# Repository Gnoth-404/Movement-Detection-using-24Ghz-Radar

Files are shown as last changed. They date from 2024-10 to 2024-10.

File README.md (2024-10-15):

# Movement-Detection-using-24Ghz-Radar
Adaptive movement detection using 24Ghz Radar and CFAR Algorithm

# Radar Movement Detection System
<p align="center">
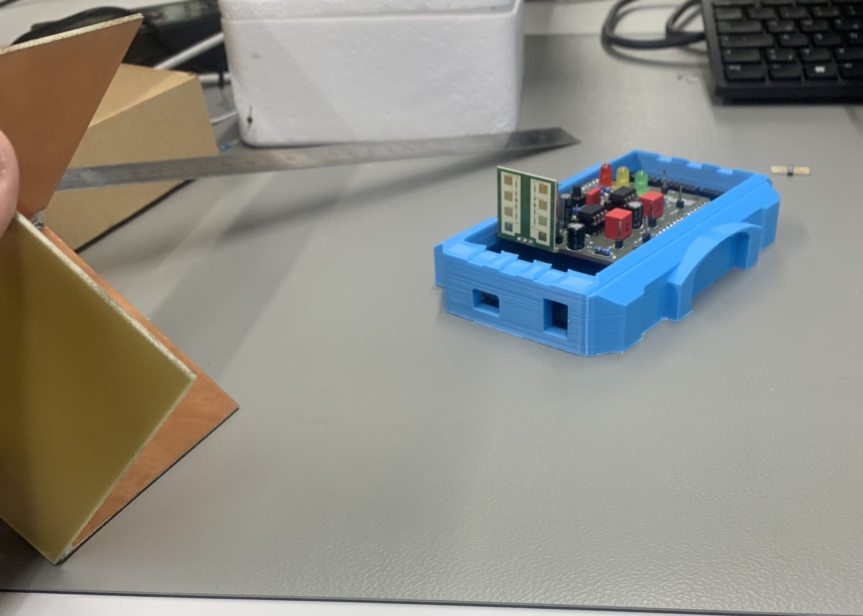
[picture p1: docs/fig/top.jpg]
  
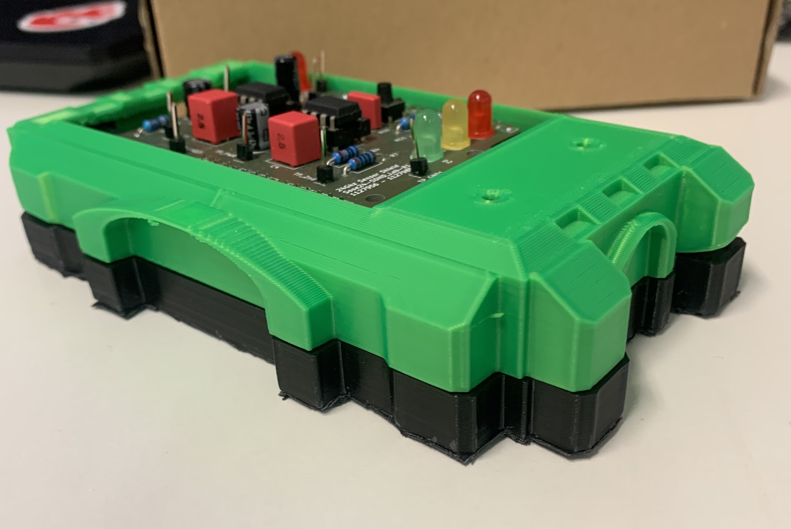
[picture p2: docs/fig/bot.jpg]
    

</p>

## Project Overview
This project implemented a radar-based movement detection system using  IPM165 radar sensor, FreeSoc2 Development Board, along with CA-CFAR algorithm. The system included custom PCB design, radar signal processing, and 3D-printed enclosure.

## Features
- 4-layer PCB design integrating IPM165 radar sensor
- Two-stage bandpass filter with gain of 300
- DMA streaming from ADC to Memory
- Signal processing using Hanning window and FFT
- Movement detection using CA-CFAR algorithm
- Custom 3D-printed enclosure

## Hardware
### PCB Design
- 4-layer PCB designed in Kicad
- Integrates IPM165 radar sensor
- Includes two-stage bandpass filter (Gain = 300)

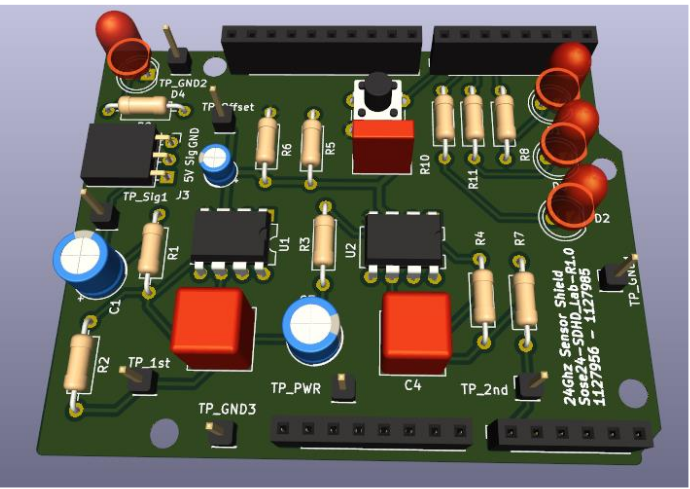
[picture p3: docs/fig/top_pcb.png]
PCB


### Enclosure
- Custom 3D-printed designed in Onshape

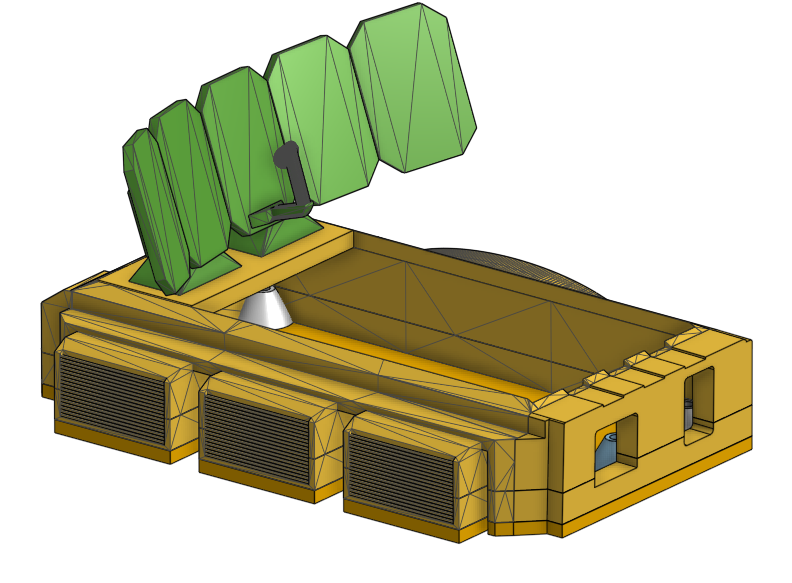
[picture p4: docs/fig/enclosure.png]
Enclosure


## Software
### Firmware (C)
- DMA streaming from ADC
- Hanning window application
- FFT implementation
- CA-CFAR algorithm for movement detection

### MATLAB
- Verification script for signal processing algorithms

## Results and Performance
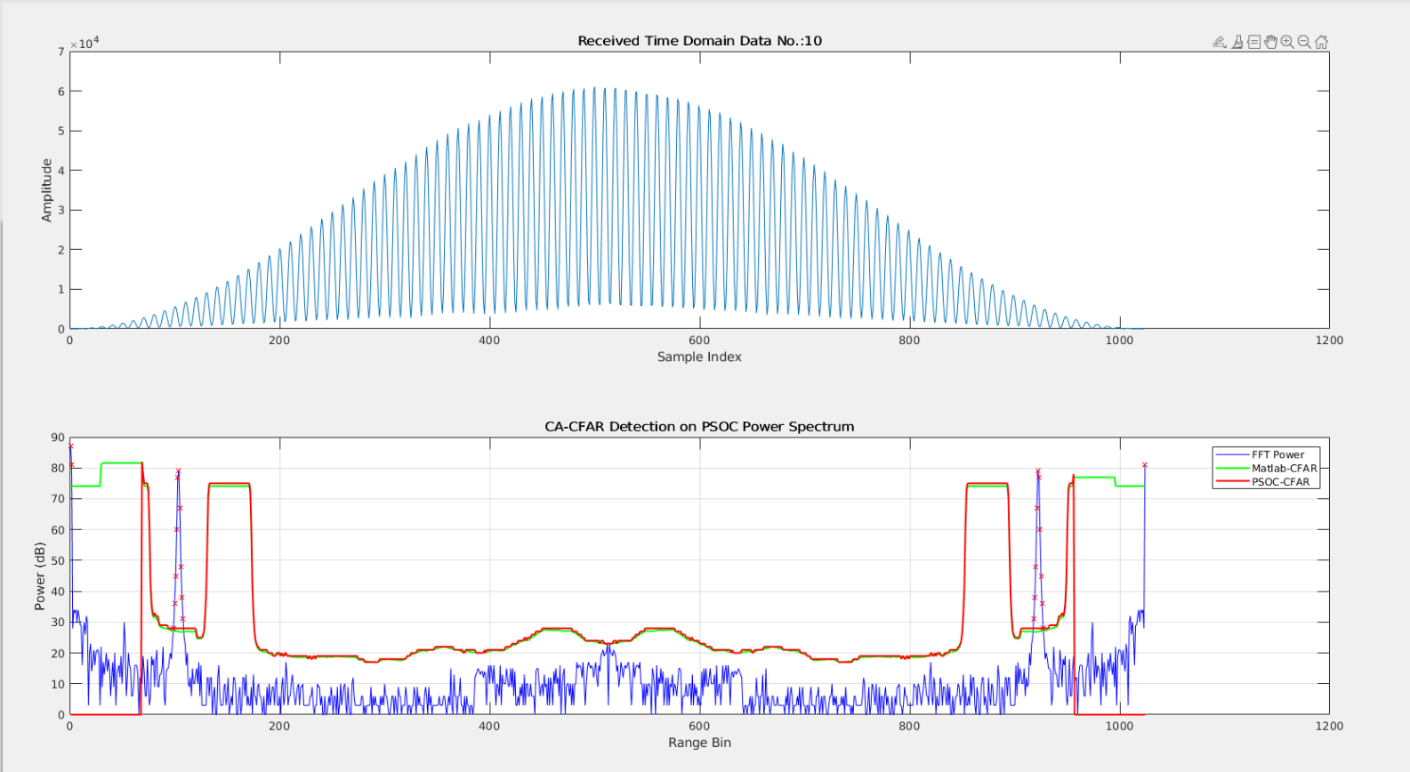
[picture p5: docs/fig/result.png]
Results


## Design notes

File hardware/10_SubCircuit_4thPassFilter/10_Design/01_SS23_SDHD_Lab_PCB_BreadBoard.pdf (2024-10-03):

# System Driven Hardware Design

### Prof. Dr.-Ing. Stephan Bannwarth

SS23

## International Master of Science

- Schematic / Layout / Breadboard-LabExcesize 1

## Agenda

### - Amplifier Schematic - PCB Constraints - Tasks - Scoring Scheme - Breadboard

SS23 | System Driven Hardware Design - © Prof. Dr.-Ing. Stephan Bannwarth | 2

### Schematic Capture: Amplifier: 4th order Bandpass

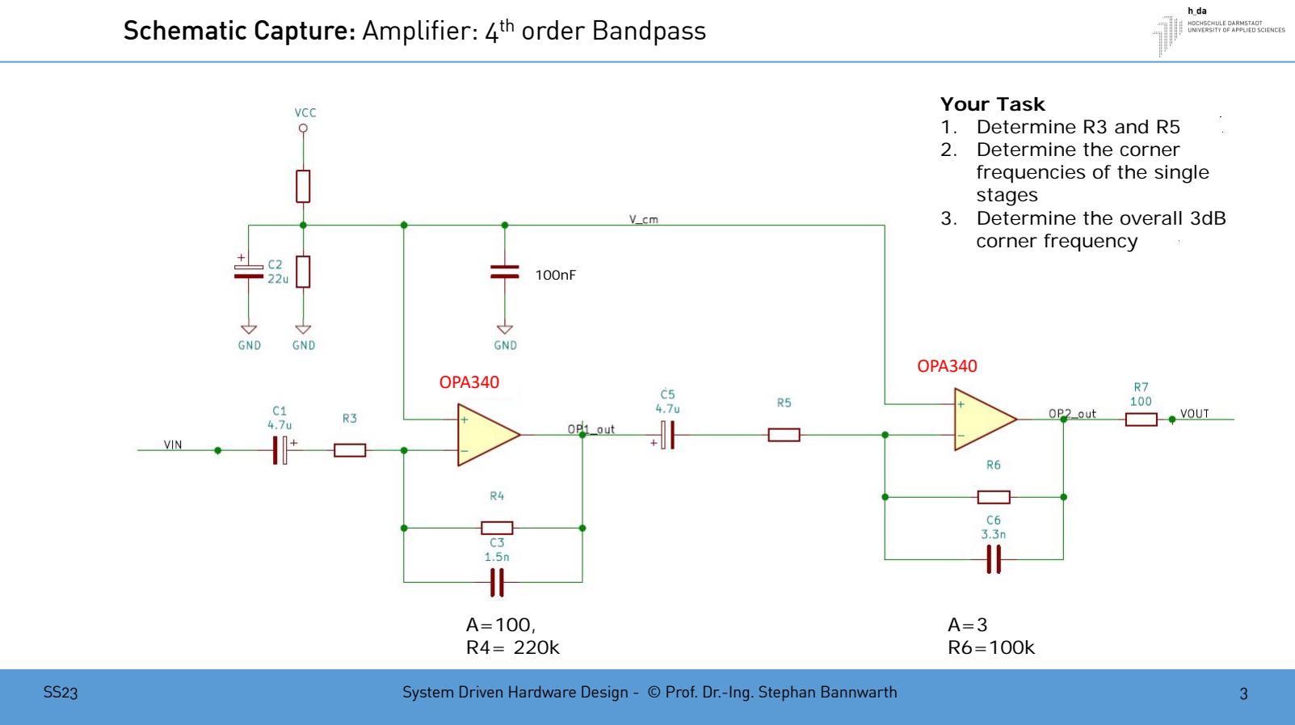
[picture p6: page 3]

SS23 | System Driven Hardware Design - © Prof. Dr.-Ing. Stephan Bannwarth | 3

100nF

A=100,
R4= 220k

A=3
R6=100k

OPA340
OPA340

Your Task
1. Determine R3 and R5
2. Determine the corner
frequencies of the single
stages
3. Determine the overall 3dB corner frequency

## Agenda

### - Amplifier Schematic - PCB Constraints - Tasks - Scoring Scheme - Breadboard

SS23 | System Driven Hardware Design - © Prof. Dr.-Ing. Stephan Bannwarth | 4

### PCB and Electronic Constraints

SS23 | System Driven Hardware Design - © Prof. Dr.-Ing. Stephan Bannwarth | 5

Amplifier
- Think about which signals should get a testpoint and write them down
- Used Device: OPA340
- Use the Operational Amplifier in a DIL8 Package
- Use an DIL8 Socket for the OpAmp

Power Supply
- Derive the Power Supply form the FreeSoc2
- Use a red LED as a control for the power supply

Hardware-Constraints
- Use a 3 pin 90° connector (i.e. connector is parallel to your board) to connect the PCB with the radar sensor
Digital Part
- Insert a Push-Button
- Use 3 LEDs (red – yellow – green) as digital control LEDs

Technology
- Use through hole technology (THT) all components.
- Use E24 series for the resistors in THT.
PCB
- Use the Arduino UNO Shield Template from KiCad. See the HowTo in Moodle.
- Separate Analog and Digital Ground as good as possible
- Stay inside the market area of the Arduino shield with your components
- Work with a 4 layer PCB: Signal – GND – Power -Signal
- Fill out the PCB Specification (Link / Elekonta Webpage)
- Only use PTH Vias: vias size 0.8mm with via drill 0.4mm
- Minimum track width: 0.20 mm
- Do not use buried vias or blind vias

### PCB and Electronic Constraints: Pin-Mapping

SS23 | System Driven Hardware Design - © Prof. Dr.-Ing. Stephan Bannwarth | 6
Bw | Pin Mapping
Lfd.Nr | Adruino - Cape / FunctionAdruino | | FreeSoc2
1 | | D0 | P[2]0
2 | | D1 | P[2]1
3 | | D2 | P[2]2
4 | | D3 | P[2]3
5 LED1 (green) | | D4 | P[2]4
6 LED2 (ornage) | | D5 | P[2]5
7 LEDe (redd) | | D6 | P[2]6
8 Push Button 9 | | D7 D8 | P[2]7 P[12]4
10 | | D9 | P[12]5
11 | | D10 | P[6]4
12 | | D11 | P[6]5
13 | | D12 | P[6]6
14 | | D13 | P6[7] & Red Use
15 | | GND | GND
16 | | AREF | NC
17 | | SDA | P[6]1
18 19 | | SCL NC | P[6]0 NC
20 | | IOREF | VDDIO_Arduino/
21 | | Reset | nReset/2 &P[12]4
22 | | 3.3V | 3.3V
23 | | 5V | 5V
24 | | GND | GND
25 | | GND | GND
26 27 Vout (Ampliffier out) | | Vin A0 | Vin/2 P15[5]
28 | | A1 | P[15]4

See Moodle for Full Table

## Agenda

### - Amplifier Schematic - PCB Constraints - Tasks - Scoring Scheme - Breadboard

SS23 | System Driven Hardware Design - © Prof. Dr.-Ing. Stephan Bannwarth | 7

### PCB and Electronic Constraints

SS23 | System Driven Hardware Design - © Prof. Dr.-Ing. Stephan Bannwarth | 8

Moodle
- Use the Project template
Tasks
- Requirement Specification for the Bandpass Design
- Design the Bandpass based on the expected input frequencies and amplitude range
- Calculate the resistors for the Amplifier based on the gain and bandwidth, use the E24 series
- Design the PCB in KiCad

Deliverables
- KiCad-Project
- Gerberfiles
- BOM
… in a zip-archive as done in the KiCad Training and descirbed in the project template

Upload – Deadline
→ See Moodle

## Agenda

### - Amplifier Schematic - PCB Constraints - Tasks - Scoring Scheme - Breadboard

SS23 | System Driven Hardware Design - © Prof. Dr.-Ing. Stephan Bannwarth | 9

## PCB Development - Scoring

SS23 | System Driven Hardware Design - © Prof. Dr.-Ing. Stephan Bannwarth | 10

No Copy and Paste From Others: 0%. All similar boards are dismissed.

40%: Schematic correct and Working Layout,
For example and not limited to:

Mechanical: Board Size correct, Mounting holes in position ERC free
DRC free
Project Info on Silk layer
All components used and correct footprints used
Mounting and Integration possible
Using the right grid and staying in one for components placing Project can be opened
60%: Well grouped schematic and layout, for example and not limited to:

All Constraints are fulfilled
Board filling is correct
Clean connection, no extra edges and turns in the tracks Schematic
- Grouped by sub functions
- Test- and ground pins defined
Layout
- Grouped subcomponents
- Tracks as short as possible

70%: Clean design with minor issues, for example and not limited to:

No Minimum tracks width
Layers used as declared
Silk layer: more than minimum Spacing
No fragile connections to solder points
Good ground connection to IC
Short distance to stabilizing caps

80%-100%: Your ideas beyond the said and further considerations.

## Agenda

### - Amplifier Schematic - PCB Constraints - Tasks - Scoring Scheme - Breadboard

SS23 | System Driven Hardware Design - © Prof. Dr.-Ing. Stephan Bannwarth | 11

### Testbench with FreeSoc 2: Use a Breadboard before you PCB is ready

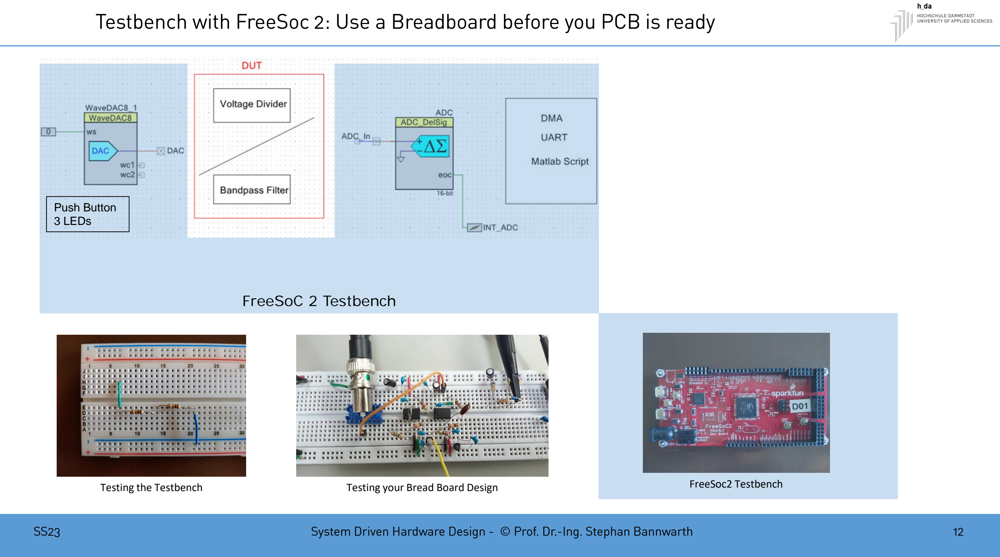
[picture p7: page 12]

SS23 | System Driven Hardware Design - © Prof. Dr.-Ing. Stephan Bannwarth | 12

FreeSoC 2 Testbench

Push Button
3 LEDs
Testing the Testbench | FreeSoc2 Testbench Testing your Bread Board Design

### Changes to the Amplifier for Breadboarding

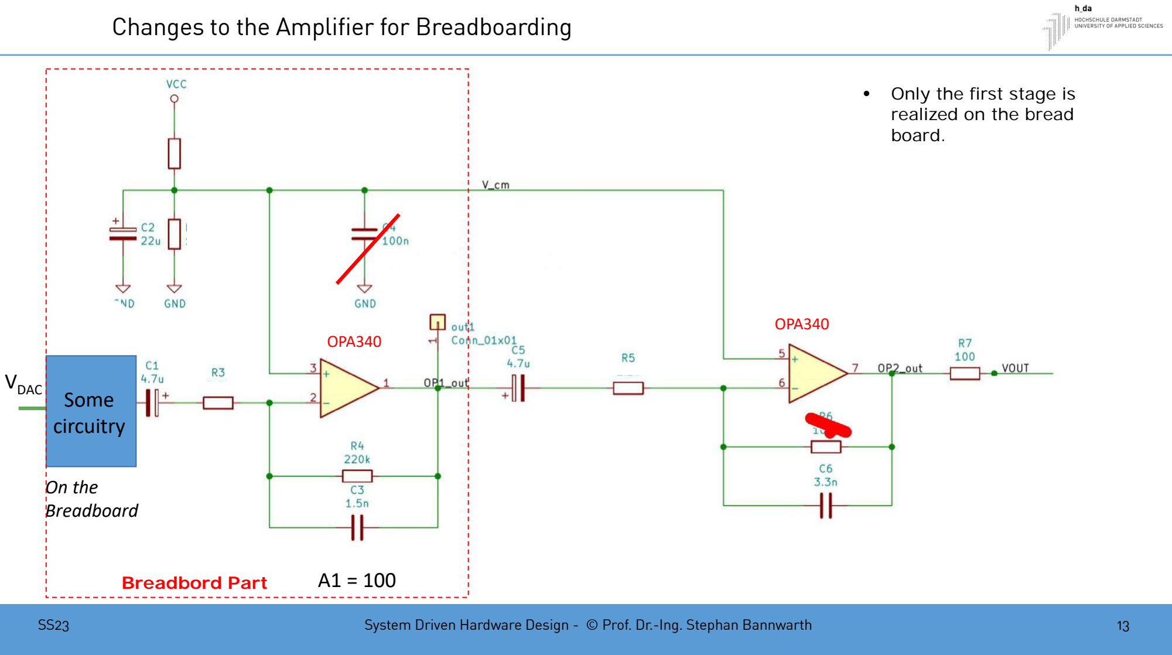
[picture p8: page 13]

SS23 | System Driven Hardware Design - © Prof. Dr.-Ing. Stephan Bannwarth | 13

A1 = 100

VDAC | Some circuitry
| On the Breadboard

OPA340

OPA340

Breadbord Part

- Only the first stage is
realized on the bread
board.

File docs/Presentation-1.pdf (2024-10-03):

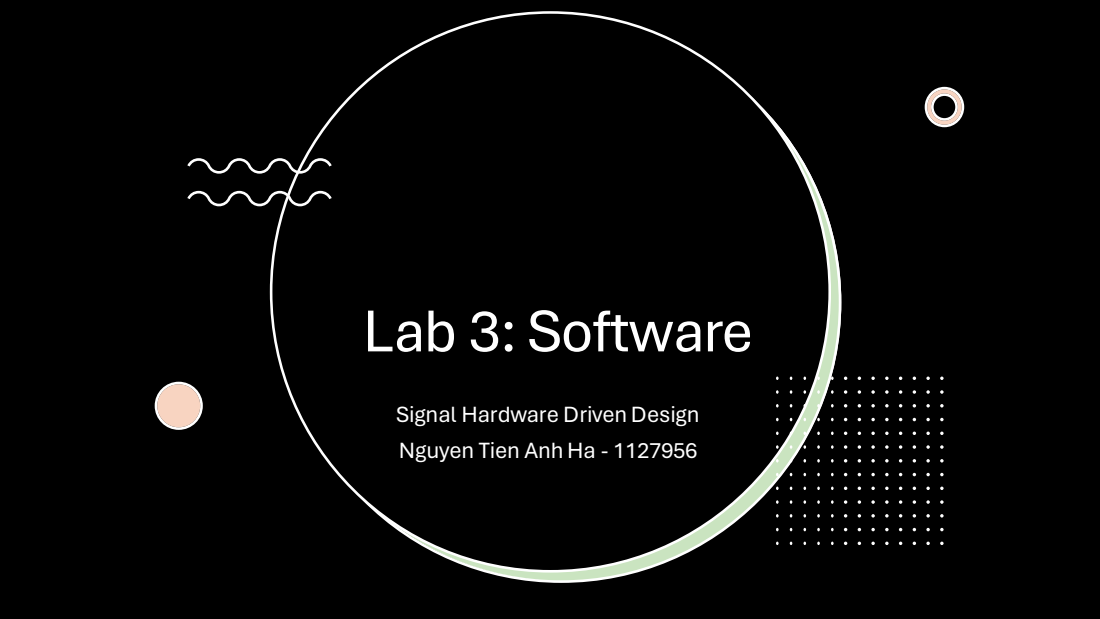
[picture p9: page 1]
Lab 3: Software

Signal Hardware Driven Design
Nguyen Tien Anh Ha - 1127956

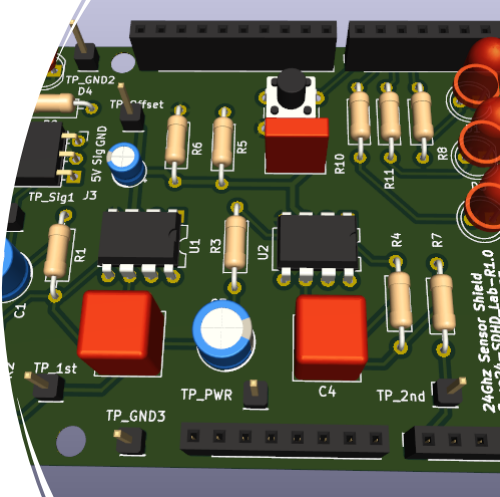
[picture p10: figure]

# Table of content

### - Hardware - Top Level Design - DMA Peripheral to Memory - DMA Wizard - State Machine - UART Transfer - Result

# Hardware

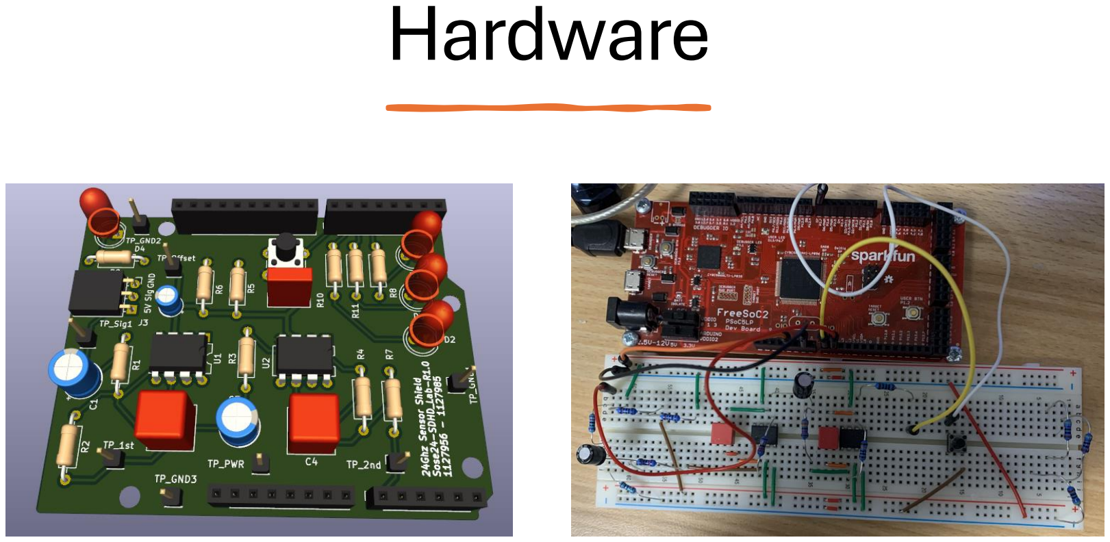
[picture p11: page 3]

# Top Level Design

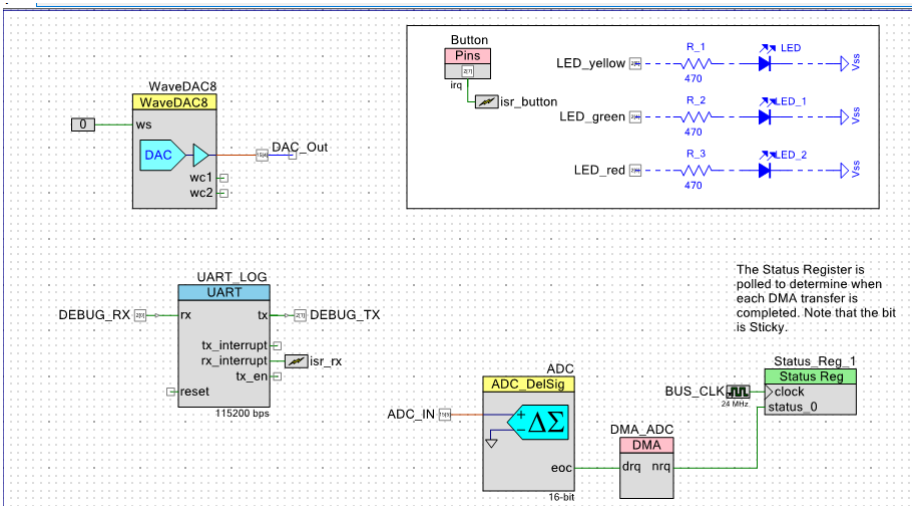
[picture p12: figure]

## DMA Peripheral to Memory

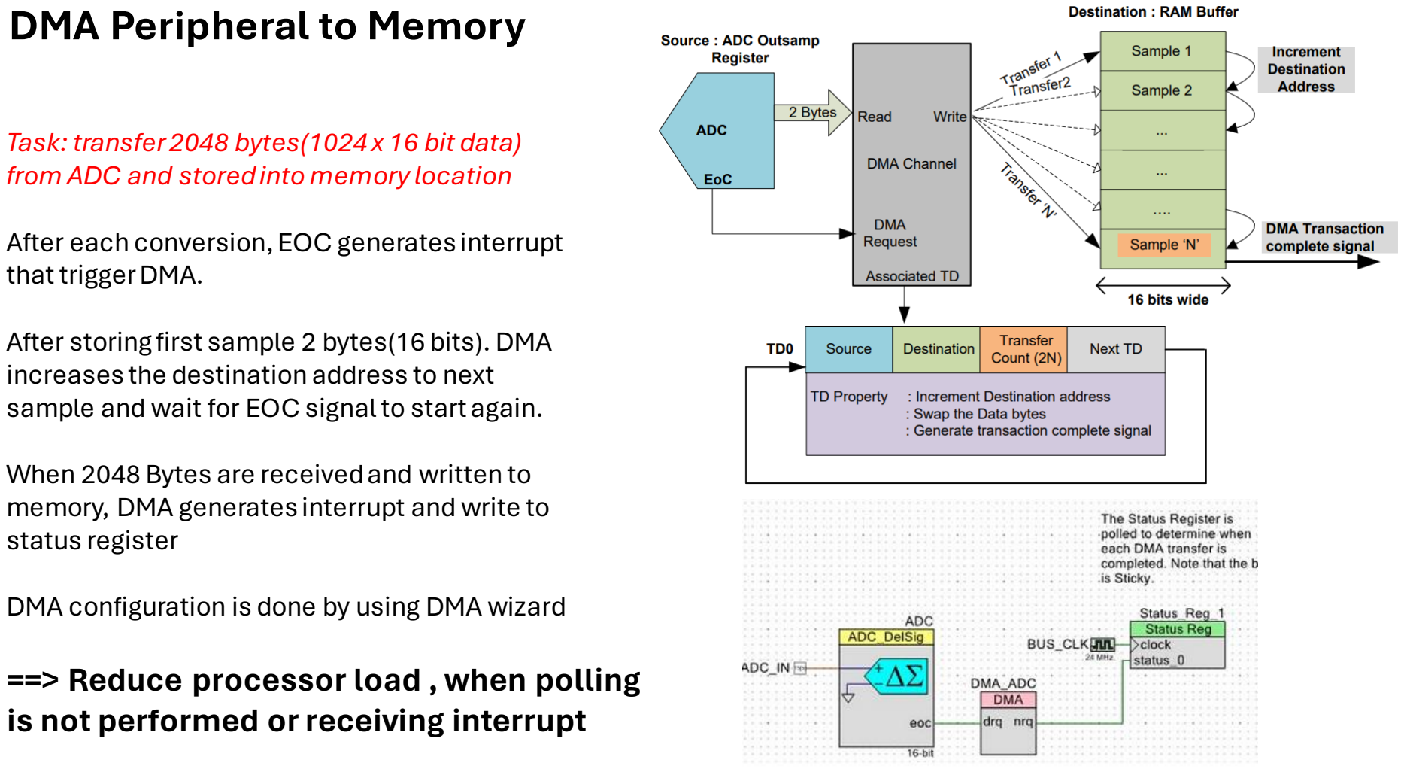
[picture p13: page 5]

Task: transfer 2048 bytes(1024 x 16 bit data) from ADC and stored into memory location

After each conversion, EOC generates interrupt that trigger DMA.

After storing first sample 2 bytes(16 bits). DMA increases the destination address to next sample and wait for EOC signal to start again.

When 2048 Bytes are received and written to memory, DMA generates interrupt and write to status register

DMA configuration is done by using DMA wizard

### ==> Reduce processor load , when polling is not performed or receiving interrupt

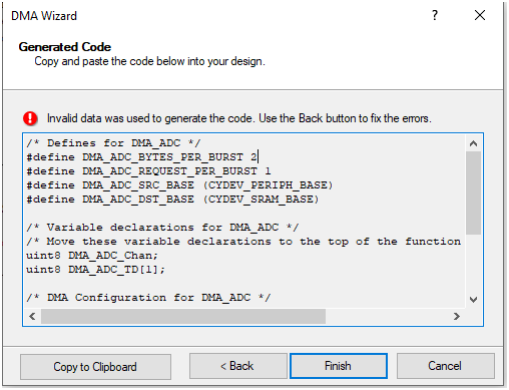
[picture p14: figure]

# DMA Wizard

# DMA Speed

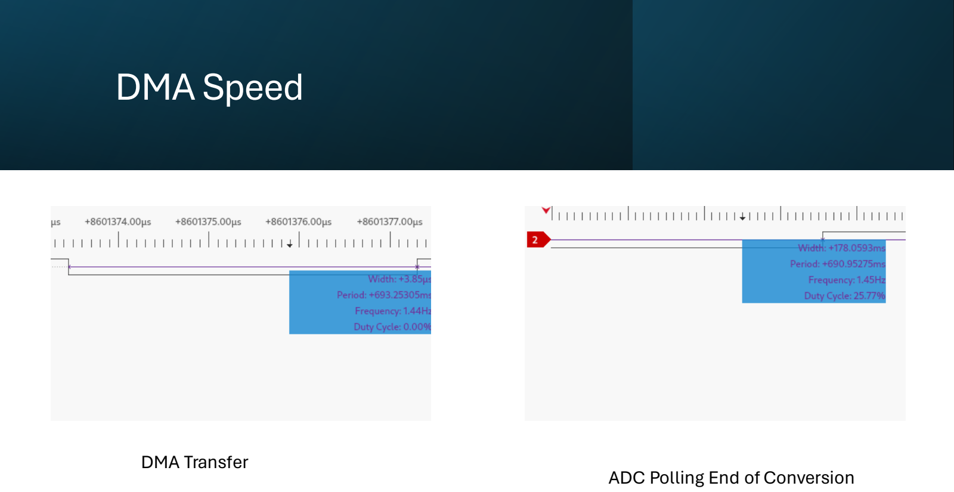
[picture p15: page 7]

DMA Transfer
ADC Polling End of Conversion

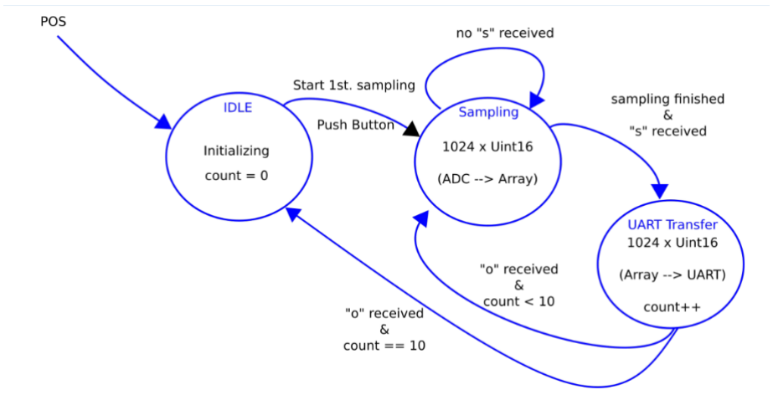
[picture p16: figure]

### - State machine design

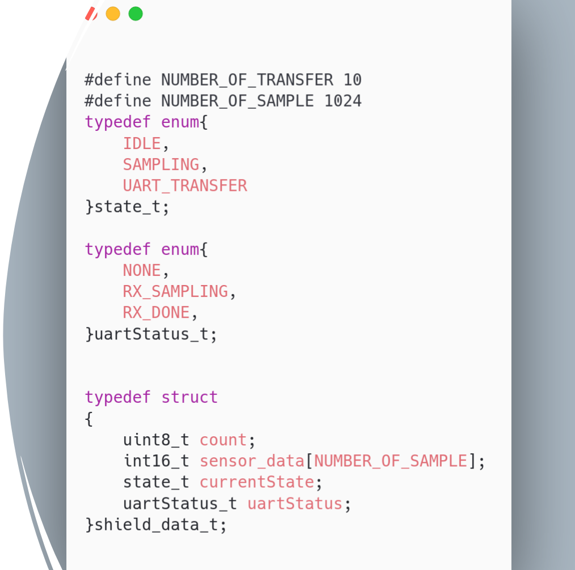
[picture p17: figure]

# Shield data

# UART Transfer to Matlab

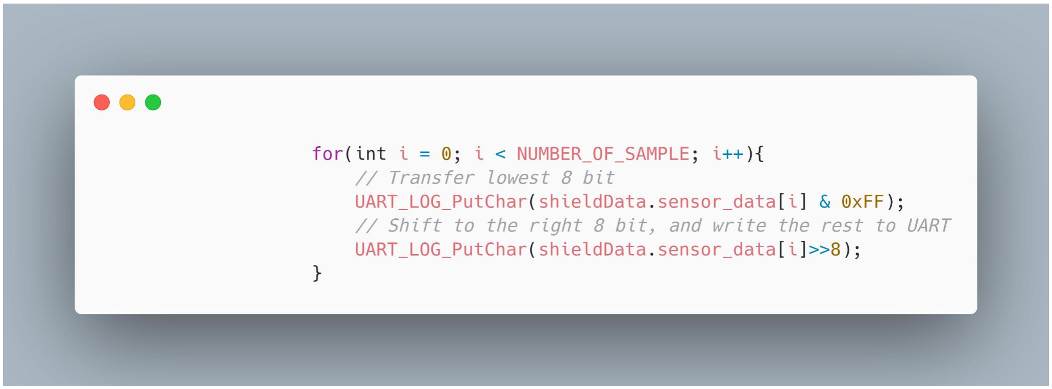
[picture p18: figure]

# Result

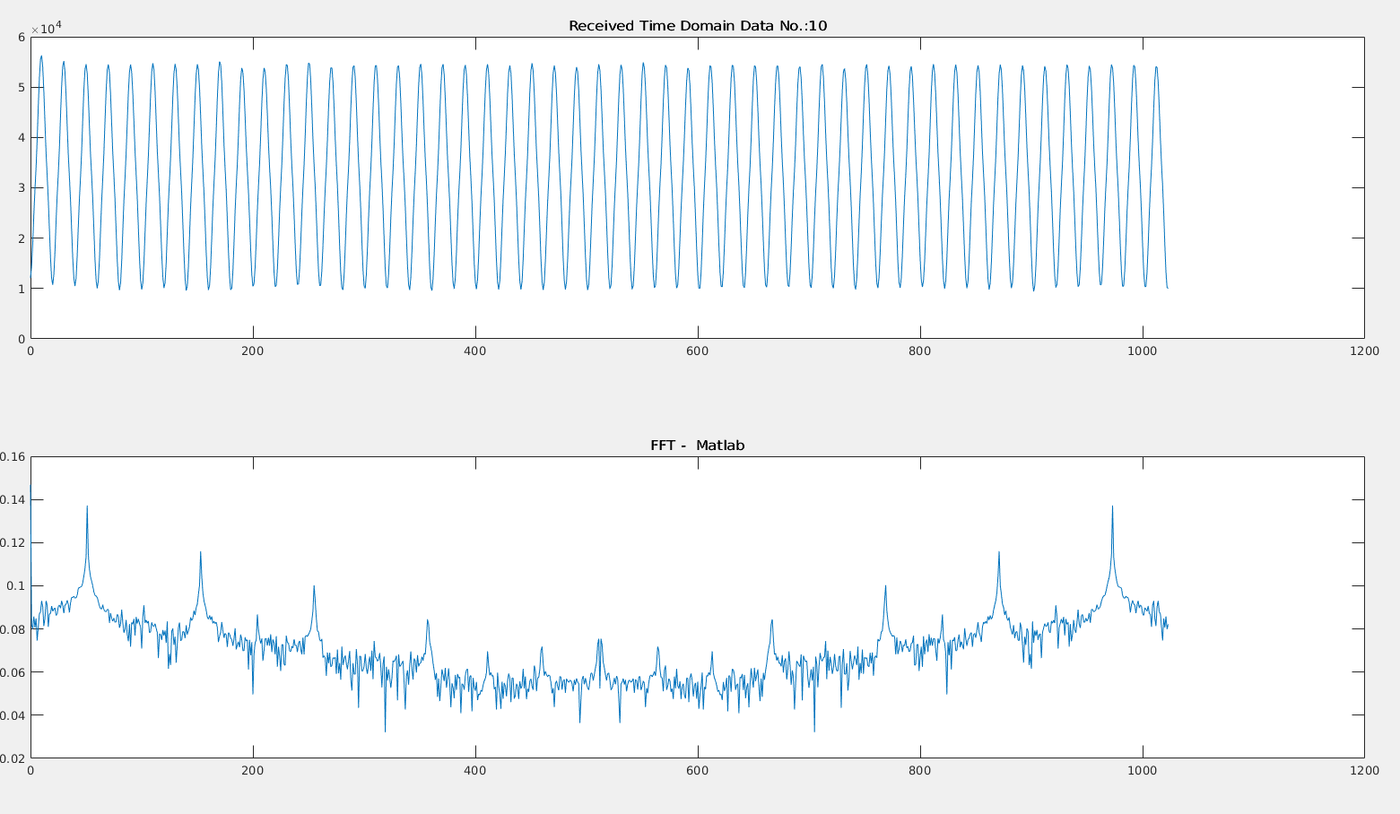
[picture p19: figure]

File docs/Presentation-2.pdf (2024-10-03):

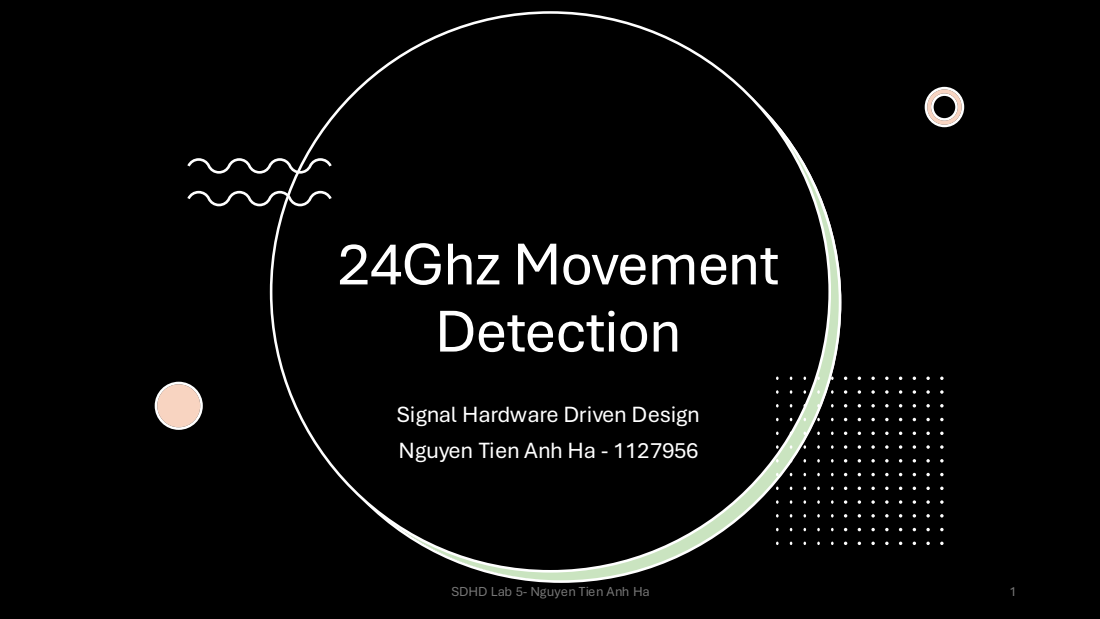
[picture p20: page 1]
24Ghz Movement Detection; SDHD Lab 5- Nguyen Tien Anh Ha

Signal Hardware Driven Design
Nguyen Tien Anh Ha - 1127956

# Table of content

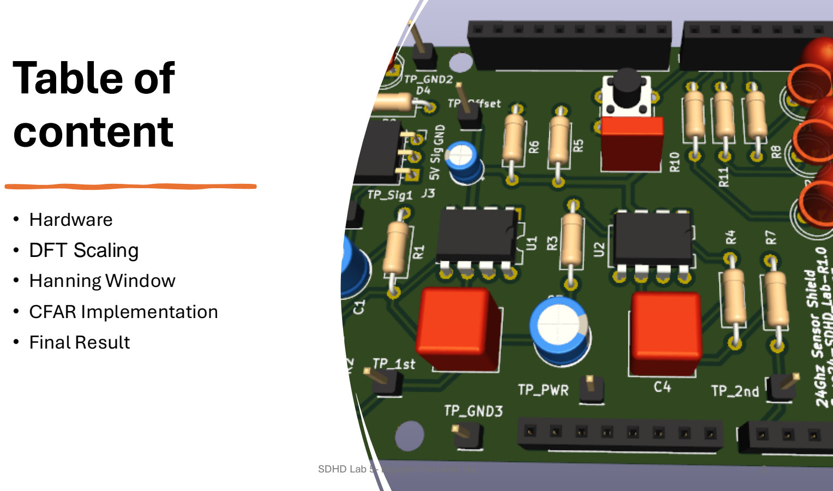
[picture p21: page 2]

# - Hardware

## - DFT Scaling

# - Hanning Window - CFAR Implementation - Final Result

# Simulation

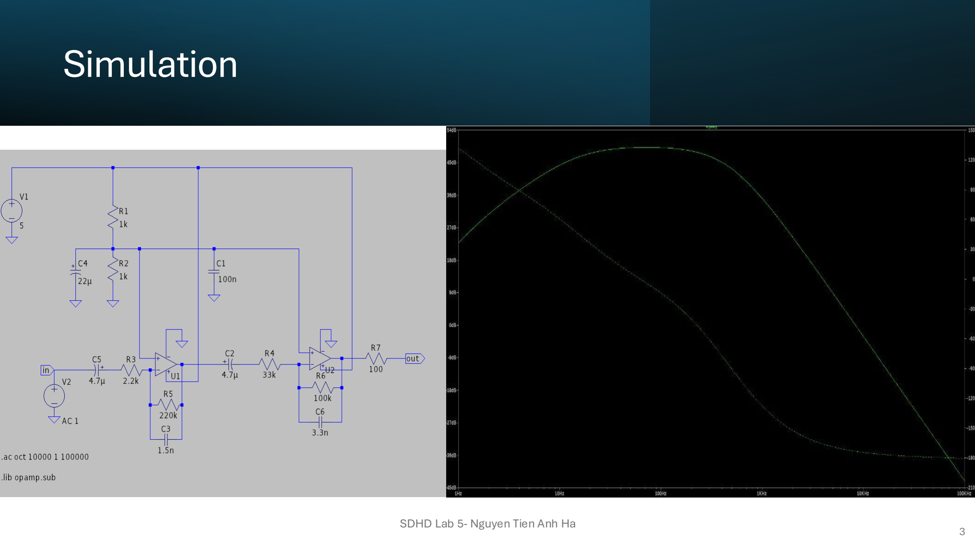
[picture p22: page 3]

3

SDHD Lab 5- Nguyen Tien Anh Ha

# Hardware

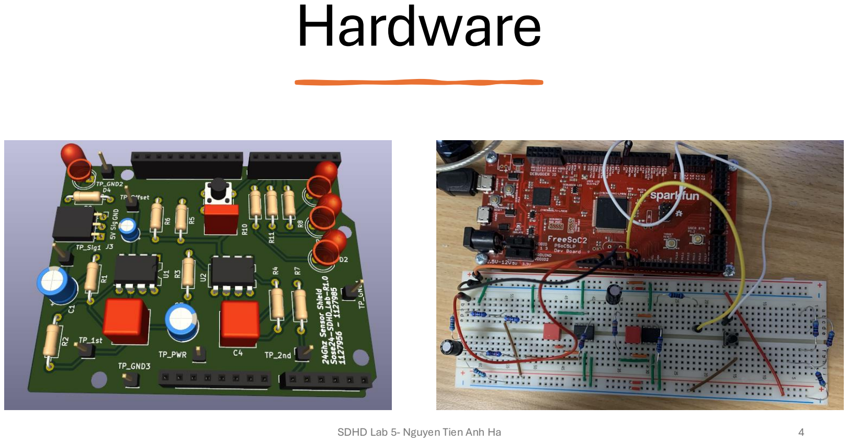
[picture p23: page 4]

# PCB and Enclosure

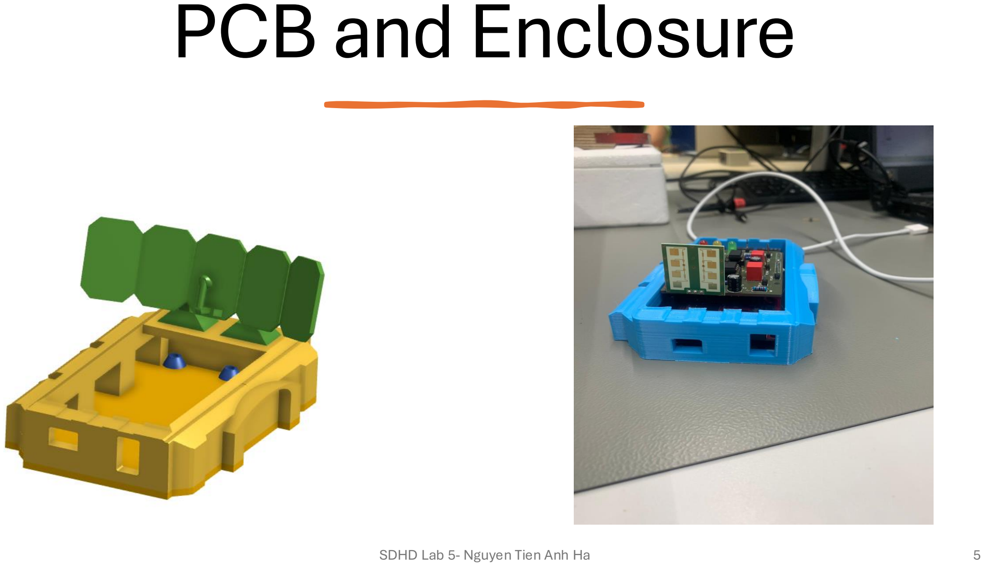
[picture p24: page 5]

# DFT Scaling Verification

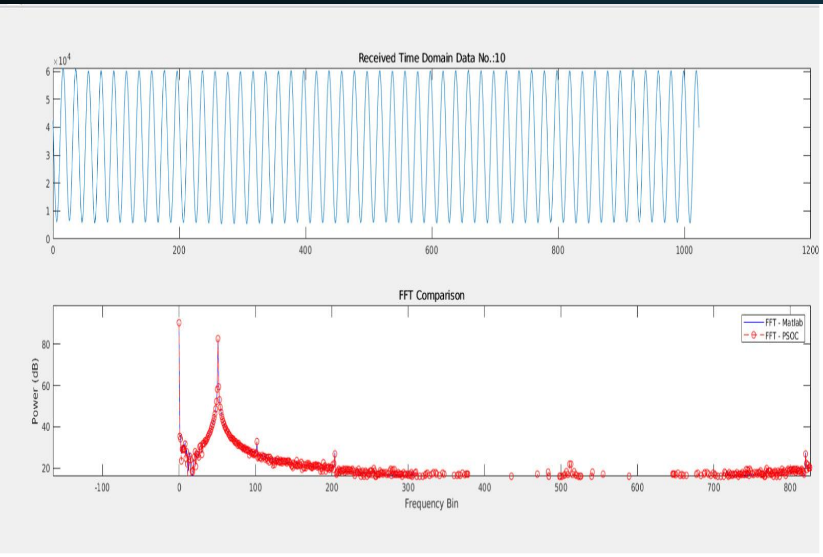
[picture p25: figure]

# •FFT libraries downsample by N samples by default

# •Divided the computed MATLAB amplitude by N to match the power spectrum from PSOC

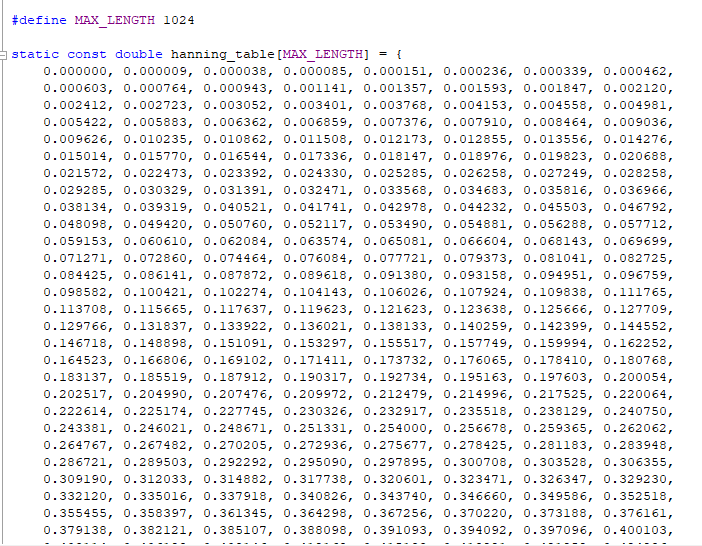
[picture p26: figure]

# Hanning Window

# Advantages:

# - Reduce spectral leakage and still provide good frequency resolution

- Easy to apply and fast to calculate.

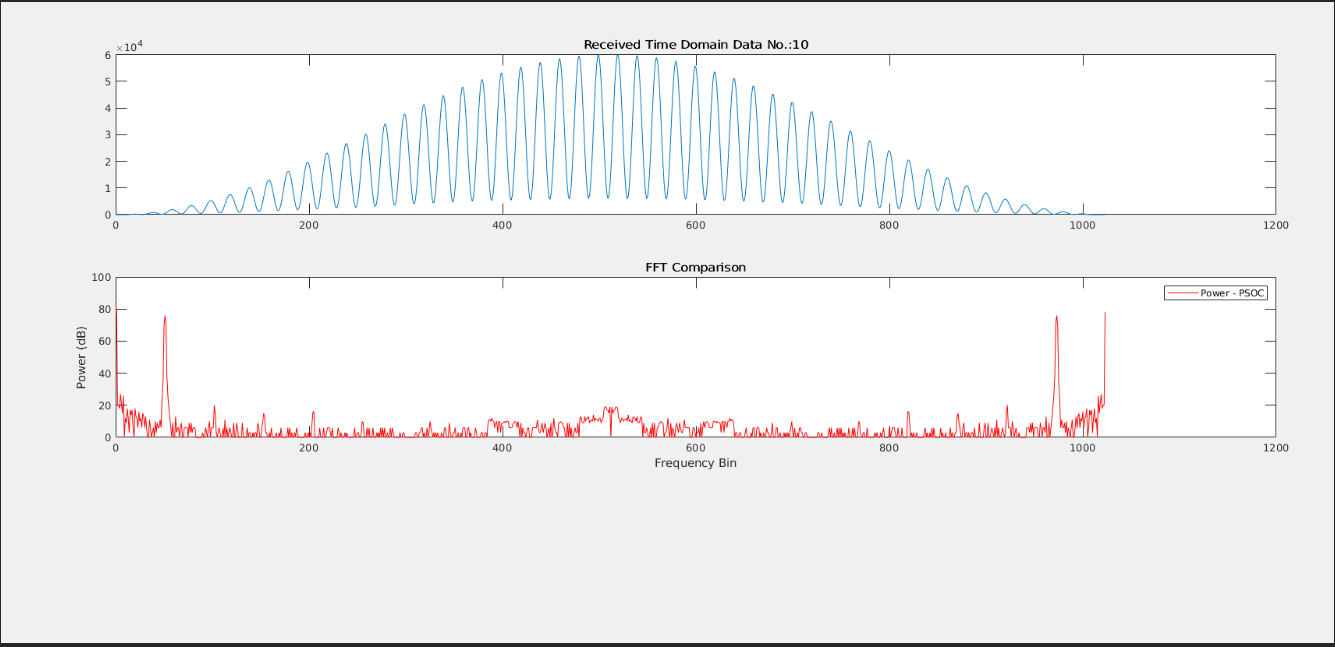
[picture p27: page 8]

# CA- CFAR

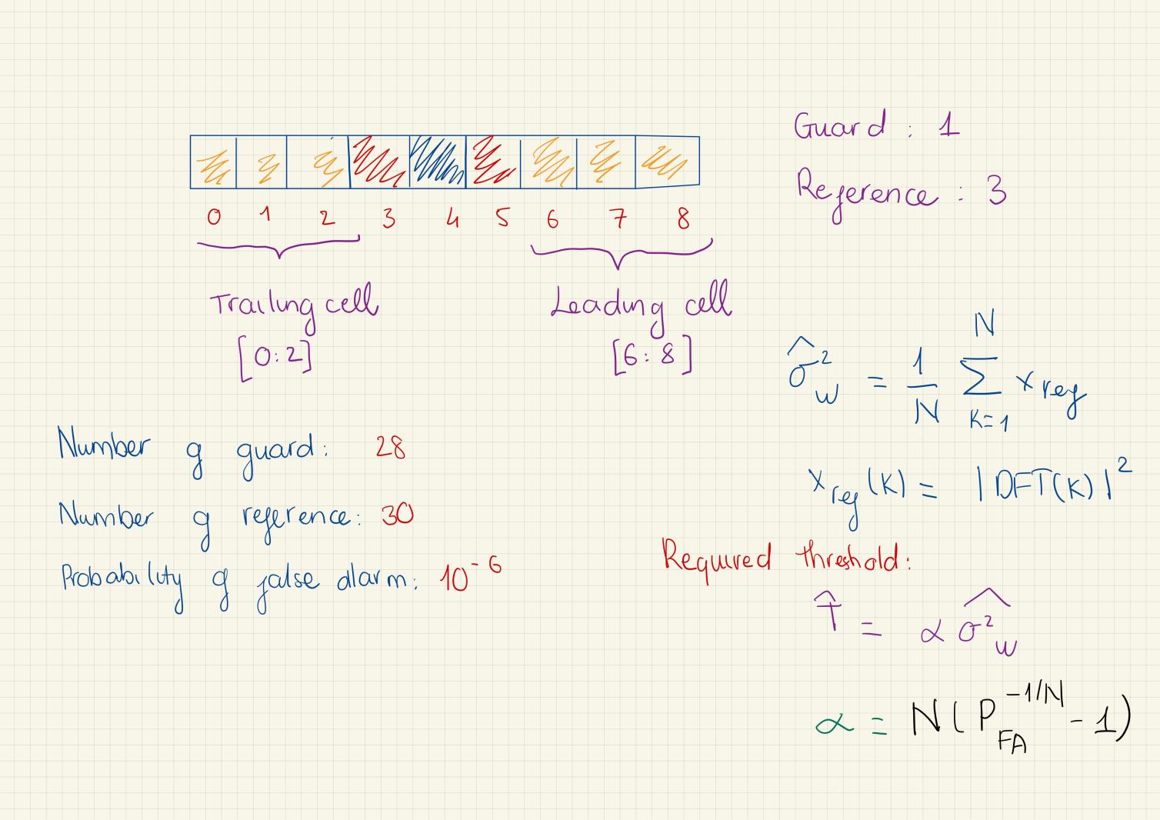
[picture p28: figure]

# Parameter

# CA – CFAR Algorithm

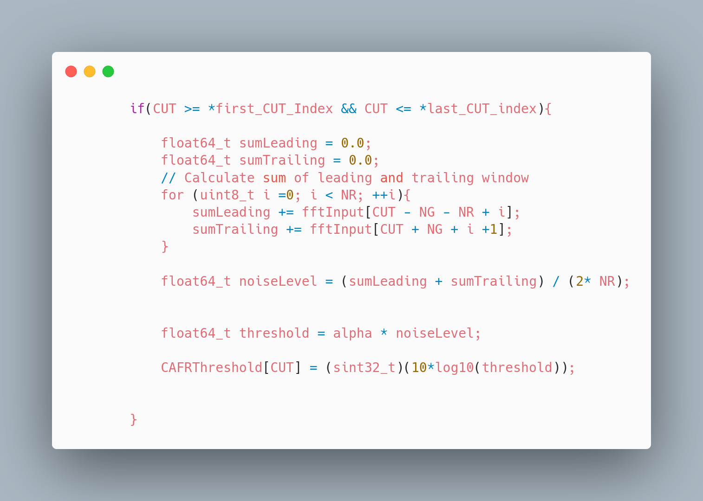
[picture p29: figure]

# Updated state machine

SDHD Lab 5


- Nguyen Tien Anh Ha | 12


# Demonstration


Thank you for listening

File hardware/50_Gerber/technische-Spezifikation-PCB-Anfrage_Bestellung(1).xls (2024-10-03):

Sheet: technischeSpezifikation
Anfrage
Leiterplattenspezifikation
 |  |  |  |  |  | Datum | 2024-05-24
Projektname: | SDHD Lab- Group 2B |  | LP-Bezeichn.: |  | 24Ghz-radar-pcb | Rev.: | 1.0
Allgemeine Anforderungen |  |  |  | Produktions-Anforderungen
IPC-A-600 G |  | Class II |  | LP-Typ: |  |  |  | Starr
RoHS kompatibel |  | Ja |  | LP-Größe: |  | +/- 0,2 mm |  | 68.5x54
UL-Zertifizierung |  | Ja |  | Nutzen: |  |  |  | Nein
Hersteller Logo |  | Ja |  | Nutzengröße: |  | +/- 0,2 mm |  | x
Date Code |  | Ja |  | Stück pro Nutzen: |  |  |  | x
E-Test |  | Ja |  | Kontur: |  |  |  | gefräst
Impedanzkontrolle |  | Ja |  | LP-Endstärke über alles: |  | +/- 10% |  | 1.6 mm
Erstmusterprüfbericht |  | Nein |  | Lagenanzahl: |  |  |  | 4
Schliffbild |  | Nein |  | Innenlagenkupfer incl. galv. Cu: |  | (µm) |  | 35
Position der UL-Nr.und Logo |  | in Daten |  | Außenlagenkupfer incl. galv. Cu: |  | (µm) |  | 35
Position Hersteller Logo |  | spezifiziert, |  | kleinste Leiterbahnbreite |  | (µm) |  | 250
und Datecode |  | Design in Cu |  | kleinster Leiterbahnabstand |  | (µm) |  | 129
 |  |  |  | Lötoberfläche: |  |  |  | chem. NI/AU
 |  |  |  | Steckergold: |  |  |  | Nein
Bohrparameter |  |  |  | Lötstoplack: |  |  |  | Grün
kleinster Bohrendurchmesser (µm) |  | 400 |  | Bestückungsdruck: |  |  |  | Top
Anzahl Bohrungen pro LP (Stück) |  | 107 |  | Farbe d. Bestückungsdruck: |  |  |  | Weiß
Langlöcher |  | Nein |  | einseitiger Viadruck: |  |  |  | Nein
Randkontaktierung |  | Nein |  | Carbondruck: |  |  |  | Nein
Backdrill |  | Nein |  | Abziehlack: |  |  |  | Nein
Blind Via |  | Nein
Blind Via / Bohrebenen |  | 1-2, 9-10
Buried Via |  | Nein |  | Basismaterial
Buried Via / Bohrebenen |  | Nein |  | Material: |  |  |  | FR4
Microfill der Blind Via |  | Nein |  | gefülltes System: |  |  |  | Ja
Pluggen der Buried Via |  | Nein |  | TG-Wert: |  | ° Celsius |  | 150
 |  |  |  | Hersteller: |  |  |  | Isola
 |  |  |  | Materialbezeichnung: |  |  |  | R 1566W / TG 150°C
 | Einkauf
Rechnungsanschrift: |  |  |  | Einzelstückzahl: |  |  |  | 1
 |  |  |  | Nutzenstückzahl: |  |  |  | x
 |  |  |  | Lieferzeit:
 |  |  |  | Versandart:
Lieferanschrift: |  |  |  | Eintrefftermin:
Kontakt Einkauf: |  |  |  |  | Kontakt Technik:
Ansprechpartner: | Holger Frank |  |  | Ansprechpartner: |  | Holger Frank
Email: | holger.frank@dalliclick.de |  |  | Email: | holger.frank@dalliclick.de
Telefon: | +49-6151-533-68262 |  |  | Telefon: | +49-6151-533-68262
Fax: |  |  |  | Fax:
Besonderheiten:
technisches Datenblatt V2 (26.11.2008) created by Bertram / Süßlin © Elekonta Marek GmbH & Co. KG www.elekonta.de

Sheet: Lagenaufbau
Datum: | 2024-05-24 | Ansprechpartner: | 0
Projektname: | 0 | Email: | 0
LP-Bezeichnung: | 0 | Telefon: | 0
Revisionsstand: | 0 | Fax: | 0
technisches Datenblatt V2 (26.11.2008) created by Bertram / Süßlin © Elekonta Marek GmbH & Co. KG www.elekonta.de

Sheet: Nutzenzeichnung
Datum: | 2024-05-24 |  | Ansprechpartner: | 0
Projektname: | 0 |  | Email: | 0
LP-Bezeichnung: | 0 |  | Telefon: | 0
Revisionsstand: | 0 |  | Fax: | 0
 |  | Nutzenzeichnung
technisches Datenblatt V2 (26.11.2008) created by Bertram / Süßlin © Elekonta Marek GmbH & Co. KG www.elekonta.de

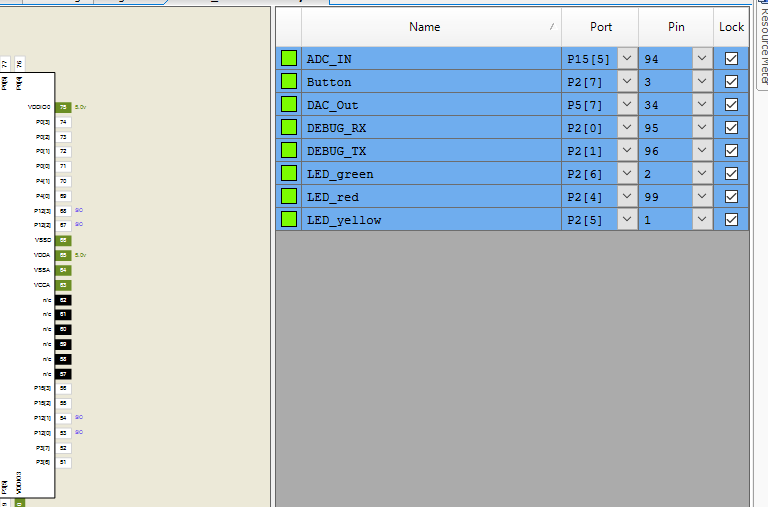
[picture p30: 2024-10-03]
docs/fig/Screenshot from 2024-10-03 14-59-23.png

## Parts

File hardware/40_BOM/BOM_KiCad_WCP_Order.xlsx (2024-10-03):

Date: | 2020-03-05 12:16 |  | Vendors | www.conrad.e
Revision: | 1.0 |  |  | www.reichelt.de
Component Count: | 10 |  |  | www.rs-components.de
 | Single Board |  |  |  |  | Order
Ref | Value | Qnty | Vendor | OrderLink | Order No. | Component Name | Order Quantitiy | single price | Total price | Cmp name | Footprint | Description
C1, C2, | 100n | 2.00 | Conrad | https://www.conrad.de/de/search.html?search=1235240%20-%2062 | 1235240 - 62 | Kemet, 100 nF 63 V 10 % 5 mm (L x B x H) 7.2 x 2.5 mm x 6.5 mm | #REF! | 0.08 € | #REF! | C | Capacitor_THT:C_Rect_L7.2mm_W2.5mm_P5.00mm_FKS2_FKP2_MKS2_MKP2 | Unpolarized capacitor
R1, R2, | 15k | 2.00 | on Stock | https://www.reichelt.de/praezisionstimer-ic-typ-555-4-5--16-v-dip-8-ne-555-dip-p13396.html?trstct=pos_0&nbc=1 |  |  | #REF! |  | #REF! | R | Resistor_THT:R_Axial_DIN0204_L3.6mm_D1.6mm_P7.62mm_Horizontal | Resistor
U1, | NE555 | 1.00 | Reichelt |  | NE 555 DIP | NE 555 DIP Timer-IC, Typ 555, DIP-8 | #REF! | 0.17 € | #REF! | NE555 | Package_DIP:DIP-8_W7.62mm_Socket | Precision Timers, DIP-8/SOIC-8
Distancae Bolt |  | 4.00 |  | https://www.conrad.de/de/p/6135-30-abstandsbolzen-l-30-mm-m3-messing-1-st-526550.html
Nut |  | 4.00 |  | https://www.conrad.de/de/p/toolcraft-888718-sechskantmuttern-m3-din-934-stahl-verzinkt-1-st-888718.html
 |  |  |  |  |  |  | #REF! |  | #REF!
 |  |  |  |  |  |  |  |  | #REF!

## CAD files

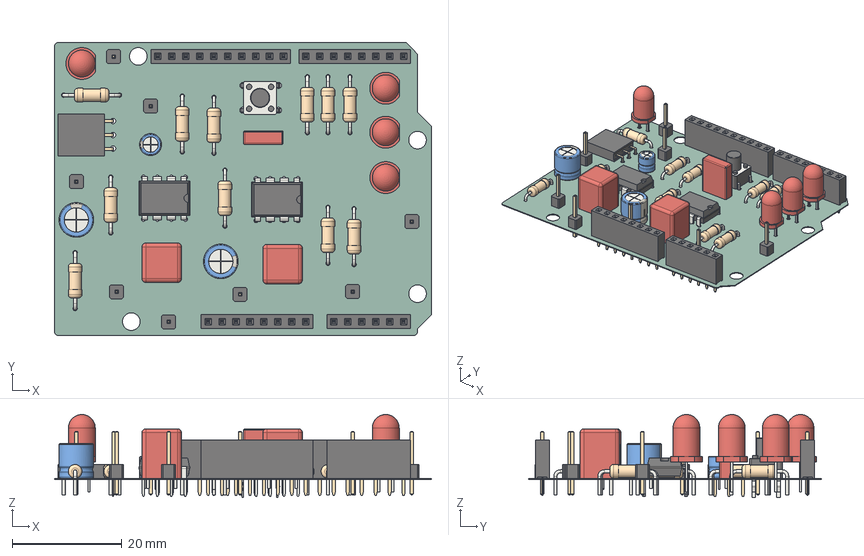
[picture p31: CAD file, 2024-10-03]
hardware/60_KiCad/SDHD_Lab.step
68.6 x 53.3 x 15.1 mm
PinSocket_1x08_P254mm_Vertical x 2
PinSocket_1x06_P254mm_Vertical
PinSocket_1x10_P254mm_Vertical
LED_D5.0mm x 4
PinHeader_1x01_P254mm_Vertical x 8
C_Rect_L72mm_W25mm_P500mm_FKS2_FKP2_MKS2_MKP2
R_Axial_DIN0207_L63mm_D25mm_P1016mm_Horizontal x 11
PinSocket_1x03_P254mm_Horizontal
SW_PUSH_6mm_h7.3mm
CP_Radial_D40mm_P200mm
DIP-8_W7.62mm x 2
C_Rect_L72mm_W72mm_P500mm_FKS2_FKP2_MKS2_MKP2 x 2
CP_Radial_D63mm_P250mm x 2
SDHD_Lab_PCB

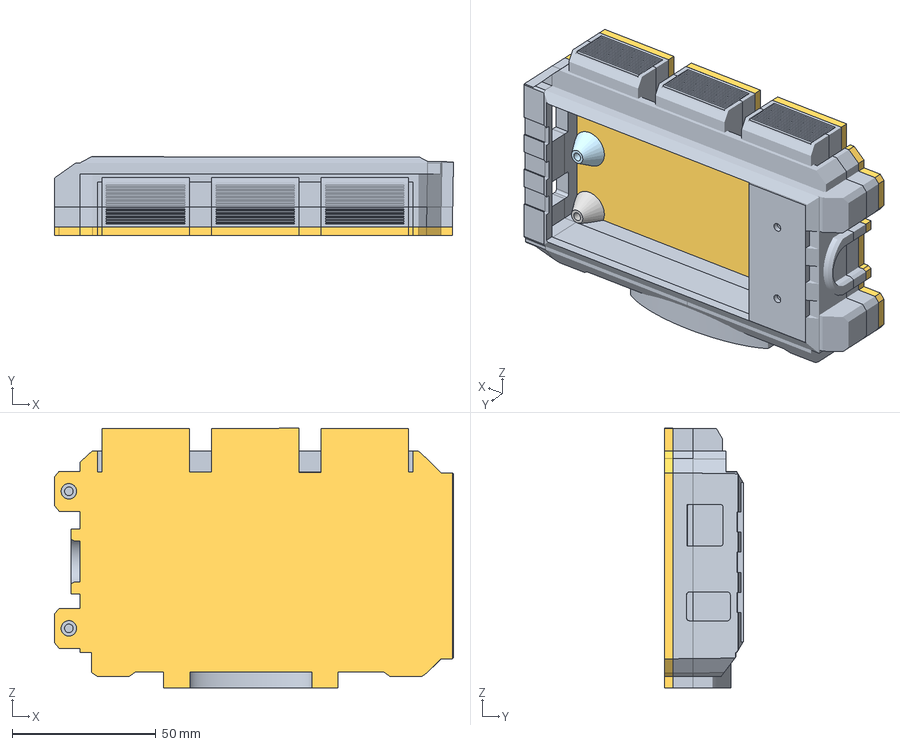
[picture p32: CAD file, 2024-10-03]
hardware/70_3D_Printed/radar_enclosure.step
138.9 x 27.5 x 90.3 mm

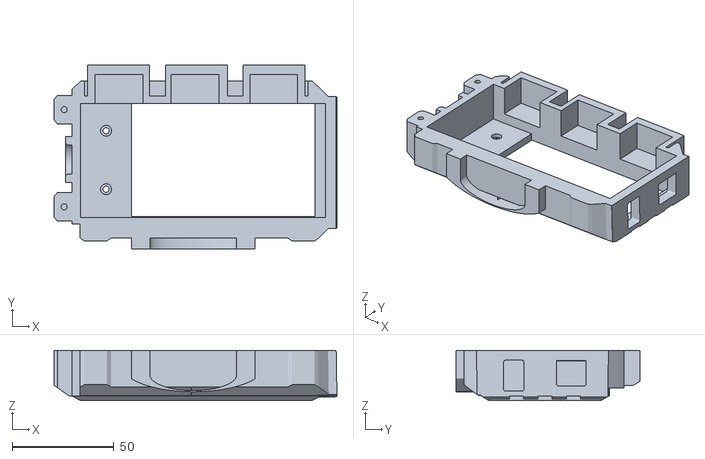
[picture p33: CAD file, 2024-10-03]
hardware/70_3D_Printed/radar_top.stl
138.9 x 90.3 x 24.6

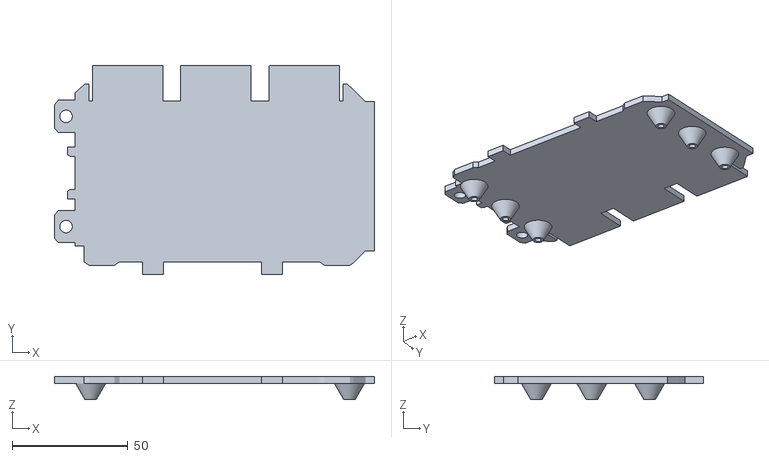
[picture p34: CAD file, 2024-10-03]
hardware/70_3D_Printed/radar_bottom.stl
138.5 x 90.3 x 10.0

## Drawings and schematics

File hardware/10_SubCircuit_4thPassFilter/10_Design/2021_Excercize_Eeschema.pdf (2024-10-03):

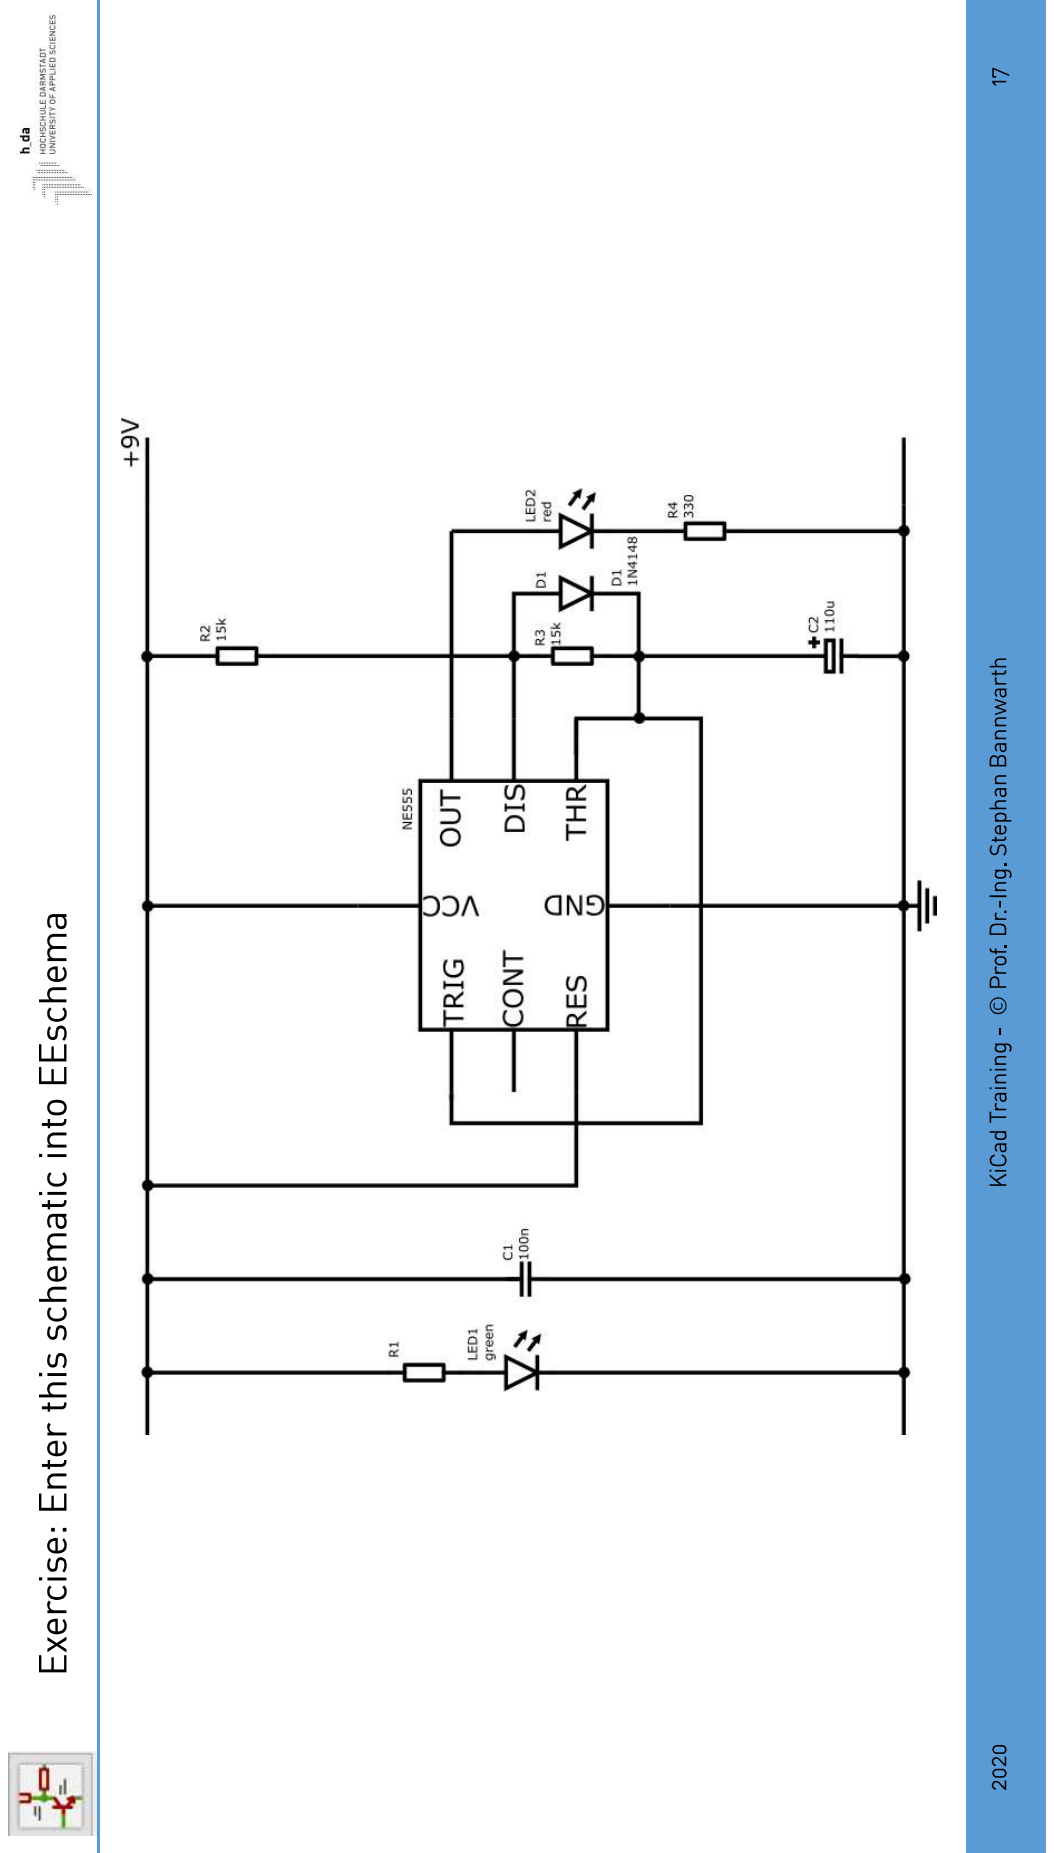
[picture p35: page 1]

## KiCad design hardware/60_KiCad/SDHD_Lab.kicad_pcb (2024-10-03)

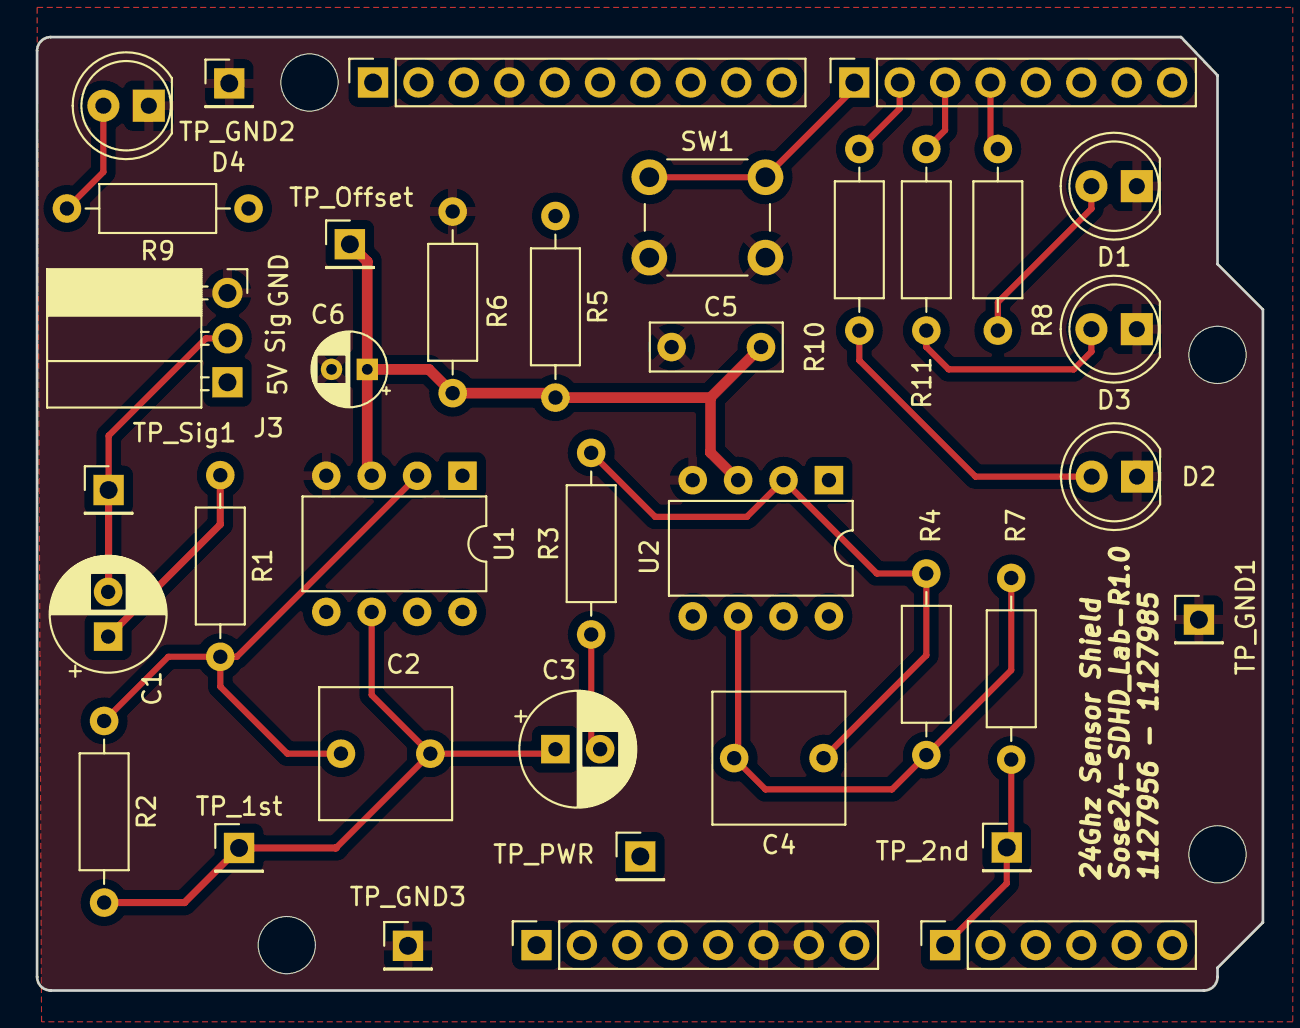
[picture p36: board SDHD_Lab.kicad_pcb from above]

Board: 4 copper layers, 68.6 x 53.3 mm, 41 parts (0 on the bottom side), 19 nets.

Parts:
C1, C3: 4.7u; CP_Radial_D6.3mm_P2.50mm
C2: 1.5n; C_Rect_L7.2mm_W7.2mm_P5.00mm_FKS2_FKP2_MKS2_MKP2
C4: 3.3n; C_Rect_L7.2mm_W7.2mm_P5.00mm_FKS2_FKP2_MKS2_MKP2
C5: 100n; C_Rect_L7.2mm_W2.5mm_P5.00mm_FKS2_FKP2_MKS2_MKP2
C6: 22u; CP_Radial_D4.0mm_P2.00mm
D1: Red_LED; LED_D5.0mm
D2: Green_LED; LED_D5.0mm
D3: Yellow_LED; LED_D5.0mm
D4: Pwr_LED; LED_D5.0mm
J1: Power; PinSocket_1x08_P2.54mm_Vertical
J2: Analog; PinSocket_1x06_P2.54mm_Vertical
J3: Conn_01x03_Socket; PinSocket_1x03_P2.54mm_Horizontal
J4: Digital/PWM; PinSocket_1x10_P2.54mm_Vertical
J5: Digital/PWM; PinSocket_1x08_P2.54mm_Vertical
MH1, MH2, MH3, MH4: MountingHole_3.2mm
R1: 2.2k; R_Axial_DIN0207_L6.3mm_D2.5mm_P10.16mm_Horizontal
R2: 220k; R_Axial_DIN0207_L6.3mm_D2.5mm_P10.16mm_Horizontal
R3: 33k; R_Axial_DIN0207_L6.3mm_D2.5mm_P10.16mm_Horizontal
R4: 100k; R_Axial_DIN0207_L6.3mm_D2.5mm_P10.16mm_Horizontal
R5, R6: 1k; R_Axial_DIN0207_L6.3mm_D2.5mm_P10.16mm_Horizontal
R7: 100; R_Axial_DIN0207_L6.3mm_D2.5mm_P10.16mm_Horizontal
R8, R9, R10, R11: 470; R_Axial_DIN0207_L6.3mm_D2.5mm_P10.16mm_Horizontal
SW1: SW_Push; SW_PUSH_6mm_H7.3mm
TP_1st: TP_1st; PinHeader_1x01_P2.54mm_Vertical
TP_2nd: TP_2nd; PinHeader_1x01_P2.54mm_Vertical
TP_GND1, TP_GND2, TP_GND3: TestPoint; PinHeader_1x01_P2.54mm_Vertical
TP_Offset: TP_Offset; PinHeader_1x01_P2.54mm_Vertical
TP_PWR: TP_5V; PinHeader_1x01_P2.54mm_Vertical
TP_Sig1: TP_Sig; PinHeader_1x01_P2.54mm_Vertical
U1, U2: OPA340P; DIP-8_W7.62mm

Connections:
+5V: J1.5, J3.1, R5.1, R9.1, TP_PWR.1, U1.7 (V+), U2.7 (V+)
/LED_GREEN: J5.2, R10.1
/LED_RED: J5.4, R8.1
/LED_YELLOW: J5.3, R11.1
/Radar_Sig: C1.2, J3.2, TP_Sig1.1
/SW_BUTTON: J5.1, SW1.1
/V_offset: C5.1, C6.1, R5.2, R6.1, TP_Offset.1, U1.3 (+), U2.3 (+)
/V_out: J2.1, R7.2, TP_2nd.1
GND: C5.2, C6.2, D1.1 (K), D2.1 (K), D3.1 (K), D4.1 (K), J1.6, J1.7, J3.3, J4.4, R6.2, SW1.2, TP_GND1.1, TP_GND2.1, TP_GND3.1, U1.4 (V-), U2.4 (V-)
unnamed: C1.1, R1.1
unnamed: C2.2, C3.1, R2.2, TP_1st.1, U1.6
unnamed: C3.2, R3.1
unnamed: C4.2, R4.2, R7.1, U2.6
unnamed: D1.2 (A), R8.2
unnamed: D2.2 (A), R10.2
unnamed: D3.2 (A), R11.2
unnamed: D4.2 (A), R9.2
unnamed: C2.1, R1.2, R2.1, U1.2 (-)
unnamed: C4.1, R3.2, R4.1, U2.2 (-)

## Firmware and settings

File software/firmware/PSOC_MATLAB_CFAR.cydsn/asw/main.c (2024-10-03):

/* ========================================
 *
 * Copyright YOUR COMPANY, THE YEAR
 * All Rights Reserved
 * UNPUBLISHED, LICENSED SOFTWARE.
 *
 * CONFIDENTIAL AND PROPRIETARY INFORMATION
 * WHICH IS THE PROPERTY OF your company.
 *
 * ========================================
*/
#include "project.h"
#include "global.h"
#include "led.h"
#include "logging.h"
#include <stdio.h>
#include <stdlib.h>
#include "fft_application.h"

#include "dsp.h"
#include "cfar.h"

typedef enum{
    IDLE,
    SAMPLING,
    UART_TRANSFER
}state_t;

typedef enum{
    NONE,
    RX_SAMPLING,
    RX_DONE,
}uartStatus_t;

typedef struct
{
    sint32_t fft_sensor_data[2*NUMBER_OF_SAMPLE];
    sint32_t mag[NUMBER_OF_SAMPLE];
    sint32_t power[NUMBER_OF_SAMPLE];
} fft_handler_t;




typedef struct
{
    uint8_t count;
    uint16_t sensor_data[NUMBER_OF_SAMPLE];
    
    fft_handler_t sensor_fft;
    sint32_t threshhold[NUMBER_OF_SAMPLE];
    state_t currentState;
    uartStatus_t uartStatus;
    uint16_t startCUTIdx;
    uint16_t stopCUTIdx;
}shield_data_t;


static shield_data_t shieldData;



CY_ISR_PROTO(isr_button_handler);

CY_ISR_PROTO(isr_rx_handler);


/* Defines for DMA_ADC */
#define DMA_ADC_BYTES_PER_BURST 2
#define DMA_ADC_REQUEST_PER_BURST 1
#define DMA_ADC_SRC_BASE (CYDEV_PERIPH_BASE)
#define DMA_ADC_DST_BASE (CYDEV_SRAM_BASE)

/* Variable declarations for DMA_ADC */
/* Move these variable declarations to the top of the function */

uint8 DMA_ADC_Chan;
uint8 DMA_ADC_TD[1];

void DMA_Config(){


    /* DMA Configuration for DMA_ADC */

    DMA_ADC_Chan = DMA_ADC_DmaInitialize(DMA_ADC_BYTES_PER_BURST, DMA_ADC_REQUEST_PER_BURST, 
        HI16(DMA_ADC_SRC_BASE), HI16(DMA_ADC_DST_BASE));

    DMA_ADC_TD[0] = CyDmaTdAllocate();

    CyDmaTdSetConfiguration(DMA_ADC_TD[0], 2048, CY_DMA_DISABLE_TD, DMA_ADC__TD_TERMOUT_EN | CY_DMA_TD_INC_DST_ADR);

    CyDmaTdSetAddress(DMA_ADC_TD[0], LO16((uint32)ADC_DEC_SAMP_PTR), LO16((uint32)shieldData.sensor_data));
    CyDmaChSetInitialTd(DMA_ADC_Chan, DMA_ADC_TD[0]);
    
}



void shieldInit(){

   shieldData.currentState = IDLE;
   shieldData.count = 1;
   shieldData.uartStatus= NONE;
   for (int16_t i=0; i< NUMBER_OF_SAMPLE; i++){
    shieldData.sensor_data[i] =0;    
    }

}


// Interrupt handler
CY_ISR(isr_button_handler)
{
    Button_ClearInterrupt();
    
    if(shieldData.currentState == IDLE)
        shieldData.currentState = SAMPLING;
    isr_button_ClearPending();
}


// UART RX Interrupt
CY_ISR(isr_rx_handler)
{
    uint8 rxRead = UART_LOG_ReadRxData();
    if (rxRead == 's')
    {
        shieldData.uartStatus= RX_SAMPLING;
    }
    if (rxRead =='o')
    {
       shieldData.uartStatus = RX_DONE;
    }
}
int main(void)
{
    CyGlobalIntEnable; /* Enable global interrupts. */
    WaveDAC8_Start();
    WaveDAC8_Enable(); 
    
    // Assign Interrupt
    isr_button_StartEx(isr_button_handler);
    isr_rx_StartEx(isr_rx_handler);
    
    ADC_Start();
    
    LED_Init();

    LOG_Init();
    shieldInit();

    DMA_Config();
    
    
    for(;;)
    {
        /* Place your application code here. */

        switch(shieldData.currentState){
            
        case IDLE:

            
            LED_Set(LED_GREEN, 1);
            
            break;
        case SAMPLING:
            LED_Set(LED_YELLOW, 1);
            ADC_StartConvert();
            CyDmaChEnable(DMA_ADC_Chan, 1);

            if (Status_Reg_1_Read()){
                    
                    // When DMA transfer finished , turn on DMA Channel 
                    // Switch to next stage       
                    ADC_StopConvert();
                    CyDmaChDisable(DMA_ADC_Chan);
                    shieldData.currentState = UART_TRANSFER;
                    
                    applyHanningWindow(shieldData.sensor_data, NUMBER_OF_SAMPLE);
                    fft_app(shieldData.sensor_data, shieldData.sensor_fft.fft_sensor_data, NUMBER_OF_SAMPLE);
                    calcPowerSpectrum(shieldData.sensor_fft.fft_sensor_data, NUMBER_OF_SAMPLE*2,shieldData.sensor_fft.mag, shieldData.sensor_fft.power);


                    CA_CFAR(shieldData.sensor_fft.mag, NUMBER_OF_SAMPLE, NUMBER_OF_GUARD, NUMBER_OF_REF, PROB_FALSE_ALARM, shieldData.threshhold,&shieldData.startCUTIdx,&shieldData.stopCUTIdx);
                    LED_Set(LED_YELLOW, 0);
                    
                    
            }

            break;
        case UART_TRANSFER:
  
                if((shieldData.count <= 10) && (shieldData.uartStatus == RX_SAMPLING)){
                
                
                    
                    shieldData.currentState = SAMPLING;
                    LED_Set(LED_RED, 1);
                    shieldData.uartStatus = NONE; 
                    for(int i = 0; i < NUMBER_OF_SAMPLE; i++){
                        // Transfer lowest 8 bit
                        UART_LOG_PutChar(shieldData.sensor_data[i] & 0xFF);
                        // Shift to the right 8 bit, and write the rest to UART
                        UART_LOG_PutChar(shieldData.sensor_data[i]>>8);
                        
                    }

                    //LOG_OUT POWER SPECTRUM
                    for (int i=0; i < NUMBER_OF_SAMPLE; i++){
                        
                        UART_LOG_PutChar(shieldData.sensor_fft.power[i]);
                        UART_LOG_PutChar(shieldData.sensor_fft.power[i] >>8);
                        UART_LOG_PutChar(shieldData.sensor_fft.power[i] >>16);
                        UART_LOG_PutChar(shieldData.sensor_fft.power[i] >>24);
                        
                    }
                    //LOG OUT THRESHOLD CFAR
                    for (int i=0; i < NUMBER_OF_SAMPLE; i++){
                        
                        UART_LOG_PutChar(shieldData.threshhold[i]);
                        UART_LOG_PutChar(shieldData.threshhold[i] >>8);
                        UART_LOG_PutChar(shieldData.threshhold[i] >>16);
                        UART_LOG_PutChar(shieldData.threshhold[i] >>24);
                        
                    }
//                    uint32_t count_detection = 0;
//                    for (int i=shieldData.startCUTIdx; i <= shieldData.stopCUTIdx; i++){
//
//                        if ( shieldData.threshhold[i] < shieldData.sensor_fft.power[i])
//                        {
//
//                            count_detection++;
//                        }                        
//                    }
//                    
//                    if (count_detection > COUNT_DETECTION_THRESHOLD){
//                        LED_Set(LED_GREEN,0);
//                        LED_Set(LED_RED, 1);
//                        CyDelay(500);
//                        LED_Set(LED_RED, 0);
//                    }

                    shieldData.count++;
                    
                }
                
                if((shieldData.count  == 11) && (shieldData.uartStatus == RX_DONE)){
                
                    
                    shieldData.currentState = IDLE;
                    shieldData.uartStatus = NONE;
                    shieldData.count=1;
                }
                
                LED_Set(LED_RED, 0);
                LED_Set(LED_YELLOW, 0);
            break;
        default:
            break;
            
        }
    }
}

/* [] END OF FILE */

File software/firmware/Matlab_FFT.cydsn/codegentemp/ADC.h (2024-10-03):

/*******************************************************************************
* File Name: ADC.h
* Version 3.30
*
* Description:
*  This file contains the function prototypes and constants used in
*  the Delta-Sigma ADC user module.
*
* Note:
*
********************************************************************************
* Copyright 2008-2017, Cypress Semiconductor Corporation.  All rights reserved.
* You may use this file only in accordance with the license, terms, conditions,
* disclaimers, and limitations in the end user license agreement accompanying
* the software package with which this file was provided.
*******************************************************************************/

#if !defined(CY_ADC_DELSIG_ADC_H)
#define CY_ADC_DELSIG_ADC_H

#include "cytypes.h"
#include "CyLib.h"
#include "CyFlash.h"
#include "cyfitter.h"
#include "cydevice_trm.h"

/* Check to see if required typedef such as float32 are available */
/* They are defined starting with cy_boot v3.30 */
/* CY_FLASH_PM_ACT_EEFLASH_REG define used to check cy_boot has v3.30 or later */    
#if !defined (CY_FLASH_PM_ACT_EEFLASH_REG)
    #error Component ADC_DelSig_v3_30 requires cy_boot v3.30 or later
#endif /* (CY_FLASH_PM_ACT_EEFLASH_REG) */


/***************************************
*       Type defines
***************************************/

/* Sleep Mode API Support */
typedef struct
{
    uint8 enableState;
    uint8 deccr;
} ADC_BACKUP_STRUCT;

/* Gain compensation structure */
typedef struct
{
    uint16 gcor;
    uint8 gval;
} ADC_GCOR_STRUCT;


/***************************************
*        Function Prototypes
***************************************/

void ADC_Start(void) ;
void ADC_Stop(void) ;
void ADC_SetBufferGain(uint8 gain) ;
void ADC_StartConvert(void) ;
void ADC_StopConvert(void) ;
uint8 ADC_IsEndConversion(uint8 retMode) ;
int8 ADC_GetResult8(void) ;
int16 ADC_GetResult16(void) ;
int32 ADC_GetResult32(void) ;
void ADC_SetOffset(int32 offset) ;
void ADC_SelectConfiguration(uint8 config, uint8 restart)
                                           ;
void ADC_SetGain(int32 adcGain) ;
int16 ADC_CountsTo_mVolts( int32 adcCounts) ;
int32 ADC_CountsTo_uVolts( int32 adcCounts) ;
float32 ADC_CountsTo_Volts( int32 adcCounts) ;
void ADC_Sleep(void) ;
void ADC_Wakeup(void) ;
void ADC_Init(void) ;
void ADC_Enable(void) ;
void ADC_SaveConfig(void) ;
void ADC_RestoreConfig(void) ;
void ADC_SetCoherency(uint8 coherency) ;
uint8 ADC_SetGCOR(float32 gainAdjust) ;
uint16 ADC_ReadGCOR(void) ;

int8 ADC_Read8(void) ;
int16 ADC_Read16(void) ;
int32 ADC_Read32(void) ;

CY_ISR_PROTO(ADC_ISR1);
CY_ISR_PROTO(ADC_ISR2);
CY_ISR_PROTO(ADC_ISR3);
CY_ISR_PROTO(ADC_ISR4);


/**************************************
*           Parameter Defaults
**************************************/

/* Default configuration values from user parameters */
#define ADC_CFG1_RESOLUTION         (16u )
#define ADC_CFG1_INPUT_RANGE        (2u)
#define ADC_CFG1_SRATE              (2000u)
#define ADC_CFG1_REFERENCE          (5u)
#define ADC_CFG1_BUFFER_GAIN        (1u)
#define ADC_CFG1_CONV_MODE          (2u)
#define ADC_CFG1_INPUT_RANGE_VALUE  (5)
#define ADC_DEFAULT_STROBE                     (0u)
#define ADC_DEFAULT_INTERNAL_CLK               (1u)
#define ADC_DEFAULT_NUM_CONFIGS                (1u)
#define ADC_DEFAULT_CHARGE_PUMP_CLOCK          (1u)
#define ADC_DEFAULT_INPUT_MODE                 (1u)
#define ADC_IRQ_REMOVE                         (0u)          /* Removes internal interrupt */
#define ADC_MI_ENABLE                          (0u)

/* Configuration constants which can be used as the "config" parameter of
*  ADC_SelectConfiguration() API.
*/
#define ADC_CFG1                (1u)
#define ADC_CFG2                (2u)
#define ADC_CFG3                (3u)
#define ADC_CFG4                (4u)


/**************************************
*           API Constants
**************************************/

/* Resolution setting constants  */
#define ADC__BITS_8 8
#define ADC__BITS_9 9
#define ADC__BITS_10 10
#define ADC__BITS_11 11
#define ADC__BITS_12 12
#define ADC__BITS_13 13
#define ADC__BITS_14 14
#define ADC__BITS_15 15
#define ADC__BITS_16 16
#define ADC__BITS_17 17
#define ADC__BITS_18 18
#define ADC__BITS_19 19
#define ADC__BITS_20 20


/* Constants for Sleep mode states */
#define ADC_STARTED                        (0x02u)
#define ADC_ENABLED                        (0x01u)
#define ADC_DISABLED                       (0x00u)

/* Ideal Gain Constant */
#define ADC_IDEAL_GAIN_CONST               (0x8000u)

/* Gvalue constant */
#define ADC_MAX_GVAL                       (0x0Fu)

/* Gvalue constants based on resolution */
#define ADC_GVAL_RESOLUTIN_8               (0x09u)
#define ADC_GVAL_RESOLUTIN_9               (0x0Au)
#define ADC_GVAL_RESOLUTIN_10              (0x0Bu)
#define ADC_GVAL_RESOLUTIN_11              (0x0Cu)
#define ADC_GVAL_RESOLUTIN_12              (0x0Du)
#define ADC_GVAL_RESOLUTIN_13              (0x0Eu)

/* Constants for SetPower(), "power" parameter */
#define ADC_LOWPOWER                       (0x00u)
#define ADC_MEDPOWER                       (0x01u)
#define ADC_HIGHPOWER                      (0x02u)
#define ADC_HIGHPOWER_1_5                  (0x03u)  /* Reserved */
#define ADC_HIGHPOWER_2_0                  (0x04u)  /* Reserved */
#define ADC_HIGHPOWER_2_5                  (0x07u)  /* Reserved */
#define ADC_POWER_MASK                     (0x07u)

/* Constants for SetBufferGain() "gain" parameter */
#define ADC_BUF_GAIN_1X                    (0x00u)
#define ADC_BUF_GAIN_2X                    (0x01u)
#define ADC_BUF_GAIN_4X                    (0x02u)
#define ADC_BUF_GAIN_8X                    (0x03u)
#define ADC_BUF_GAIN_MASK                  (0x03u)

/* Constants for IsEndConversion() "retMode" parameter */
#define ADC_RETURN_STATUS                  (0x01u)
#define ADC_WAIT_FOR_RESULT                (0x00u)

/* Constants for input range parameter */

#define ADC_IR_VSSA_TO_VREF                (0x00u)
#define ADC_IR_VSSA_TO_2VREF               (0x01u)
#define ADC_IR_VSSA_TO_VDDA                (0x02u)
#define ADC_IR_VSSA_TO_6VREF               (0x03u)
#define ADC_IR_VNEG_VREF_DIFF              (0x04u)
#define ADC_IR_VNEG_2VREF_DIFF             (0x05u)
#define ADC_IR_VNEG_6VREF_DIFF             (0x06u)
#define ADC_IR_VNEG_VREF_2_DIFF            (0x07u)
#define ADC_IR_VNEG_VREF_4_DIFF            (0x08u)
#define ADC_IR_VNEG_VREF_8_DIFF            (0x09u)
#define ADC_IR_VNEG_VREF_16_DIFF           (0x0Au)

/* Constants for ADC reference parameter */

#define ADC_INT_REF_NOT_BYPASSED           (0x00u)
#define ADC_INT_REF_BYPASSED_ON_P03        (0x01u)
#define ADC_INT_REF_BYPASSED_ON_P32        (0x02u)
#define ADC_EXT_REF_ON_P03                 (0x03u)
#define ADC_EXT_REF_ON_P32                 (0x04u)
#define ADC_INT_REF_VDDA_4                 (0x05u)
#define ADC_INT_REF_VDDA_3                 (0x06u)
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

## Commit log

2024-10-03 Uploaded firmware
    - 3 Projects
    - Sending ADC Data to Matlab
    - Sending FFT Data to Matlab
    - CFAR Algorithm in C
    [Matlab_FFT.sdf, PSOC_FFT.sdf, PSOC_MATLAB_CFAR.sdf]
2024-10-03 Uploaded Hardware desciption
    - Simulation
    - Kicad Project
    - Gerber file
    [BOM_KiCad_WCP_Order.xlsx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]
2024-10-03 Uploaded 3D printed file
    [radar_bottom.stl, radar_enclosure.step, radar_top.stl]
2024-10-15 Upload PCB image
2024-10-15 Add pcb image to wiki
